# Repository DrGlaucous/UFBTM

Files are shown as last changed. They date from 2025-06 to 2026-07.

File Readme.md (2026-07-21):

# UFBTM
~~*Unnamed Full Body Tracking modules*~~

*They have a name now...*
# Mr. Tracker
A cheap, compact, and open-source realtime tracking module built with slimeVR and the ESP32.

<div style="display: flex;">
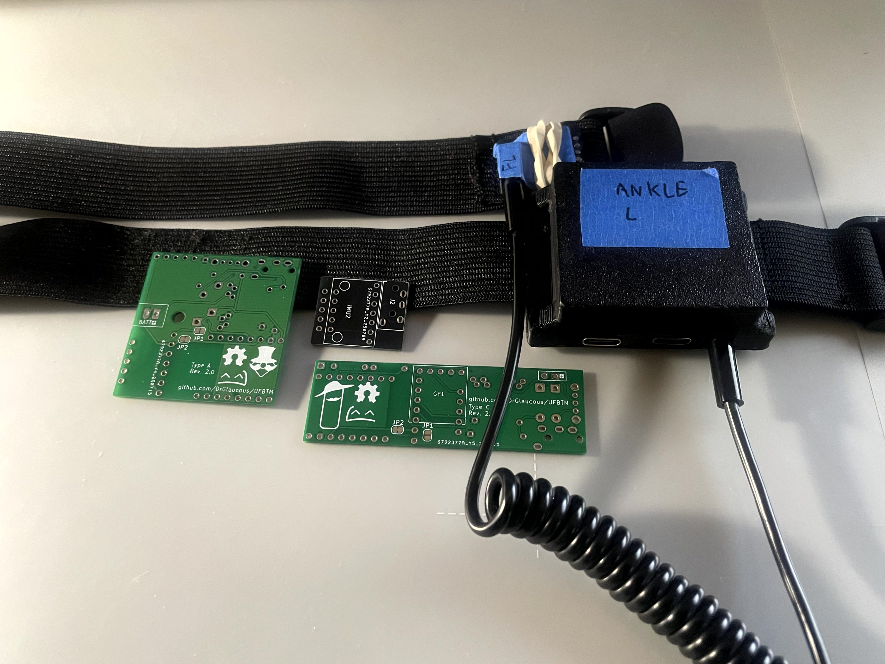
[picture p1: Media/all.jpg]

</div>

## Design goal
<details open>
<summary>
    Details
</summary>

The components for these trackers have been chosen to be **exclusively through-hole** for ease of assembly (at a slight cost of a larger size)

The main IMU this design is based around is the BMI160, primarily for its low cost and small breakout footprint. This IMU is notorious for drifting, so it is also paired with a GY-271 magnetometer to mitigate some of the drift (depending on use location, the magnetometers may need to be disabled due to poor magnetic field).

<figure align = "center">
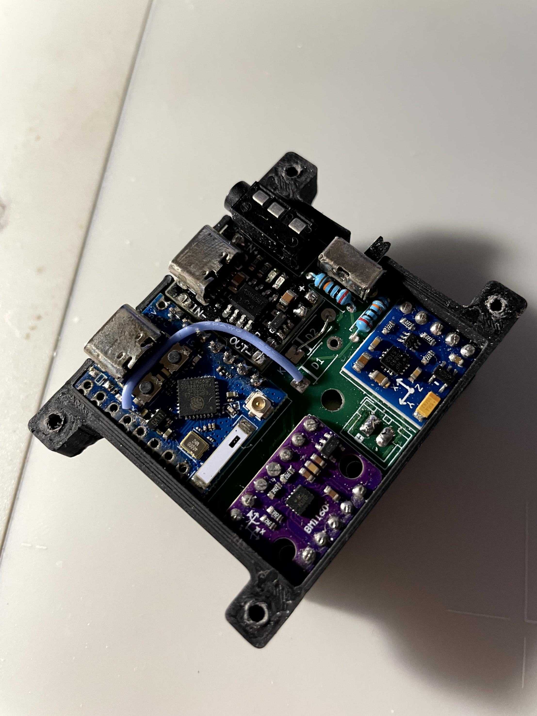
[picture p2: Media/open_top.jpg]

</figure>

This idea is by no means novel; I'm not even the first person to use the components I'm using, but I'm attempting to take a cost approach here. The full tracking set (10 modules + 5 extenders) can potentially be as low as $100 USD without print time costs or filament prices.

Assembly should be quick and reliable with no need for SMD or rework, which is something other modules of this size can't do.

The module uses TRRS (4 ring) aux jacks to connect between the main board and its extender, providing a robust connection that can last many plug cycles and be easily replaced if the wire goes bad.

Battery life of these trackers should be comparable to official ESP8266-based slime trackers, though I've only personally used them for about 6-8 hours at a time.

</details>

## Compatibility

<details>
<summary>
    MCU
</summary>

### MCU
For the microcontroller, this board can support anything with the "superMini" form factor with the 8 or 9 pin length (including the s3 variants, though I haven't tested the firmware with the s3)

<div class="image-row" style="display:flex;flex-wrap:wrap">
    <div class="image-col" style="flex:50%">
        <div class="grid-item">
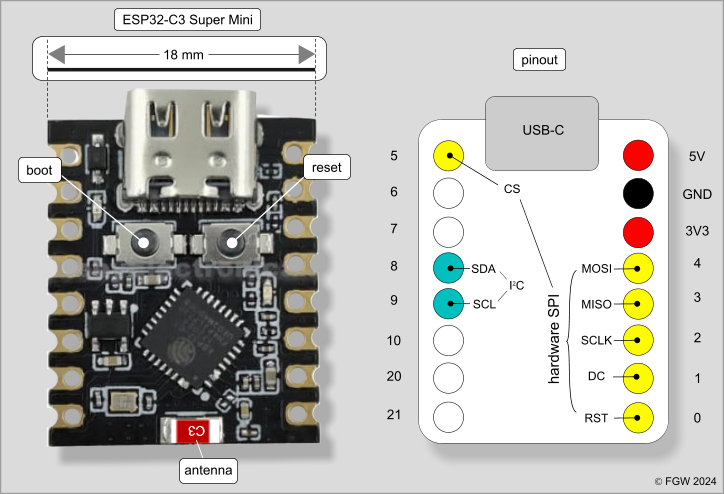
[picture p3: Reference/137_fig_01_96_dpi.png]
            
        </div>
    </div>
    <div class="image-col" style="flex:50%">
        <div class="grid-item">
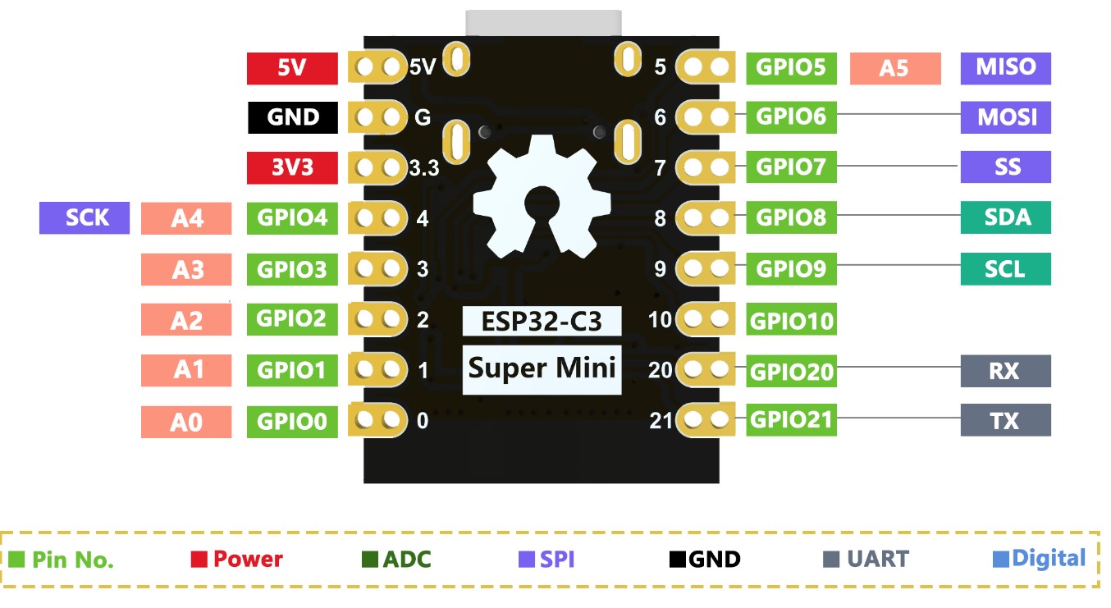
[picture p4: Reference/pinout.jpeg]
            
        </div>
    </div>
</div>

> [!NOTE]
> ***Check to make sure the +5v, GND, and +3.3v on the board match the "standard" superMini layout as seen above! Some boards like to mix them around, like the one below. That one WILL NOT WORK.***

<figure align = "center">
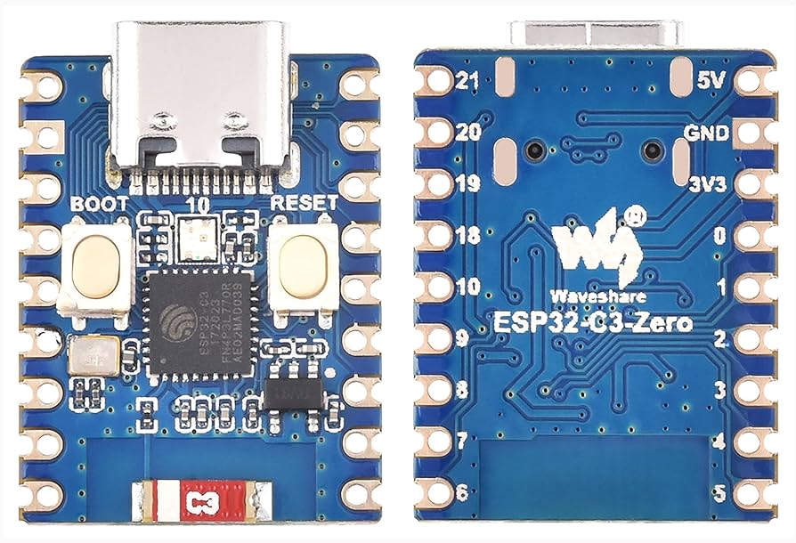
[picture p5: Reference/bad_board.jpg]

<figcaption align = "center"><i>Note how the power pins are on the opposite side from the normal superMini board</i></figcaption>
</figure>

---
My preference is the variant commonly labeled as "Pro Minis" or "C3 Minis" because [the normal "Supermini" modules can have issues with antenna reception](https://peterneufeld.wordpress.com/2025/03/04/esp32-c3-supermini-antenna-modification/), depending on which ones you get. *(and it's a mixed bag, so you're never really sure if you're getting the right ones)*

The "Pro Mini" modules have a larger antenna that seems further spaced from the rest of the components. They're distinct enough that you always know you're getting the right type of board, and as far as I can tell, haven't been complained about online. They also have a place for an external antenna, should you ever want to go that route. SuperMini v2 modules also work well, but are typically more expensive.

<figure align = "center">
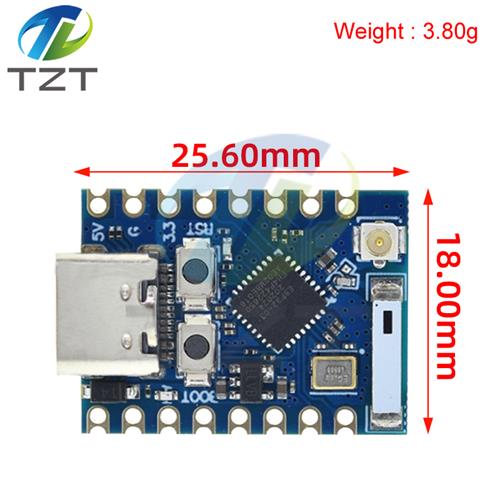
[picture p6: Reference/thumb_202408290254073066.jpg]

<figcaption align = "center"><i>An example of an "ESP32 C3 pro mini"</i></figcaption>
</figure>

</details>

---

<details>
<summary>
    IMU
</summary>

### IMU
The IMU can be anything that matches the BMI160 breakout form-factor.
This includes:
- The BMI160 itself
- The LSM6DS3 (*note: getting these from AliExpress will often just get you a re-badged BMI160.*) These aren't officially supported by the upstream slimeVR firmware as-of-writing, but are supported by my custom fork.
- Slimevr "Mumo" boards hosting a CM-45686 module
- [Mofflab](https://moffshop.deyta.de/products/lsm6dsv-module) LSM6DSV modules *(I'm sure there are other vendors of these that I haven't mentioned, but these are all I could find while searching the internet. Join the SVR discord if you want to find better sources)*

<div class="image-row" style="display:flex;flex-wrap:wrap">
    <div class="image-col" style="flex:50%">
        <div class="grid-item">
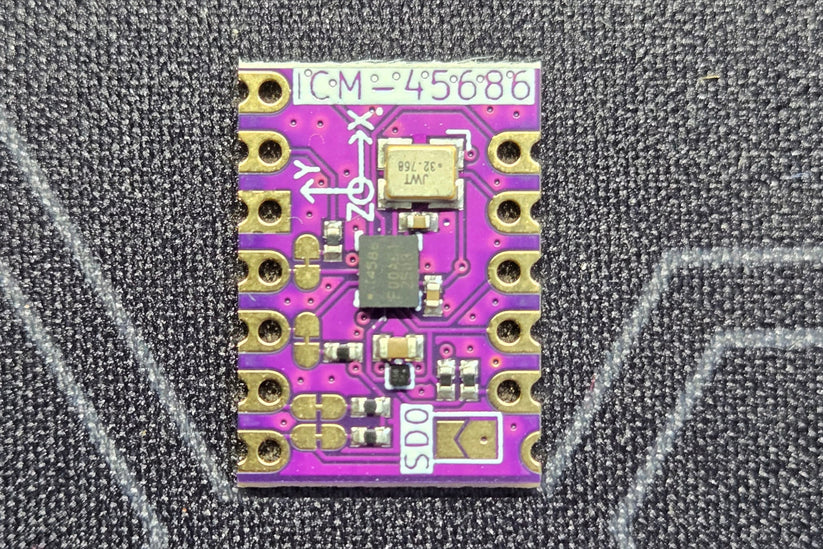
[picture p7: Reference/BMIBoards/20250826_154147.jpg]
            
        </div>
        <div class="grid-item">
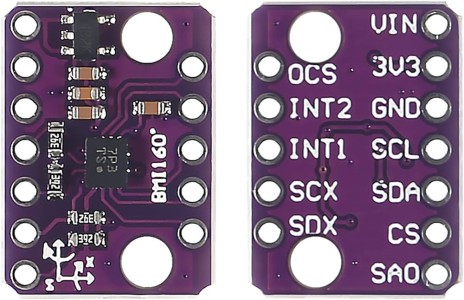
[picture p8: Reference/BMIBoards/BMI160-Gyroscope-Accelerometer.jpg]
            
        </div>
    </div>
    <div class="image-col" style="flex:50%">
        <div class="grid-item">
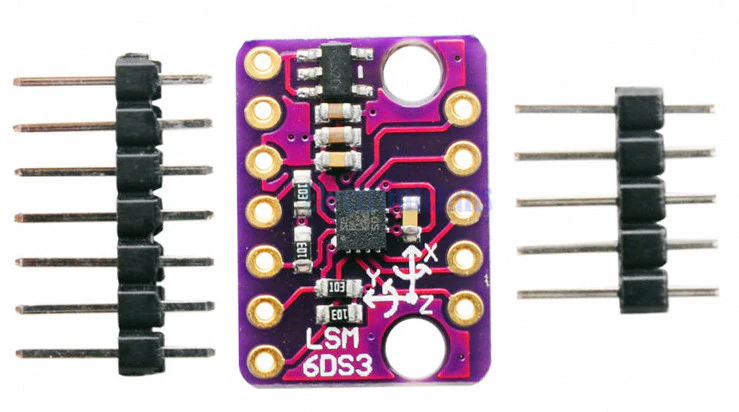
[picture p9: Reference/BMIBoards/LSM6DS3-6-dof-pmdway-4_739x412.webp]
            
        </div>
        <div class="grid-item">
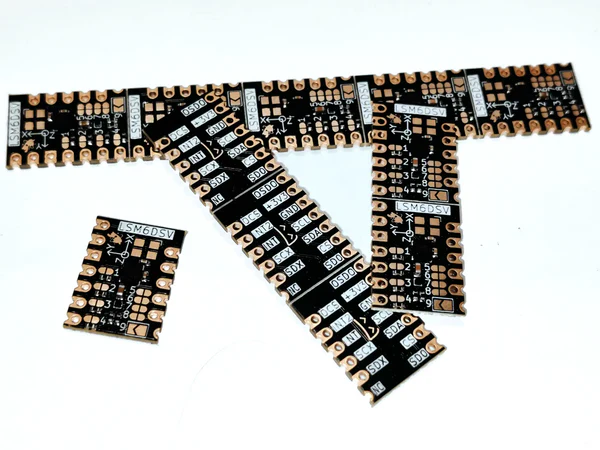
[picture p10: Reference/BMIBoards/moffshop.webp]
            
        </div>
    </div>
</div>

</details>

---

<details>
<summary>
    Magnetometer
</summary>

### Magnetometer

The PCB was designed to hold a GY-271 magnetometer breakout board.
These boards are common enough, but tend to have several variants of actual magnetometer on them, including:
- HMC5883L
- QMC5883L
- QMC5883P

All these are supported by my fork of the slimeVR firmware *(with the BMI160 and LSM6DS3, I haven't tested with the mumos or mofflab boards, but if the IMU on those are good enough, you shouldn't need a magnetometer anyway)*, but they have distinct registers, so you will have to check which one you have. (as-of-writing, the QMC5883P is the most common of these)

<figure align = "center">
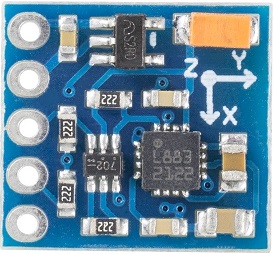
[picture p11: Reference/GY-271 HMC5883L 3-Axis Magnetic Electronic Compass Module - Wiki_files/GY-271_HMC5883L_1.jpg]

</figure>

</details>

---

<details>
<summary>
    Charger
</summary>

### Charger

One of the most compact jellybean chargers are the `LX-LBES` chargers. They tend to come in 2 distinct sizes, and it's unreliable which one you might get. The PCB can support either of them though, so this shouldn't be a problem. These are also commonly labeled as `TP4057` charger boards.

Just make sure it's the `LX-LBES` module and not the other variants like the `LX-MILC` or `LX-LBC3`, both of which are similarly sized, but are incompatible.

<figure align = "center">
<div class="image-row" style="display:flex;flex-wrap:wrap">
    <div class="image-col" style="flex:50%">
        <div class="grid-item">
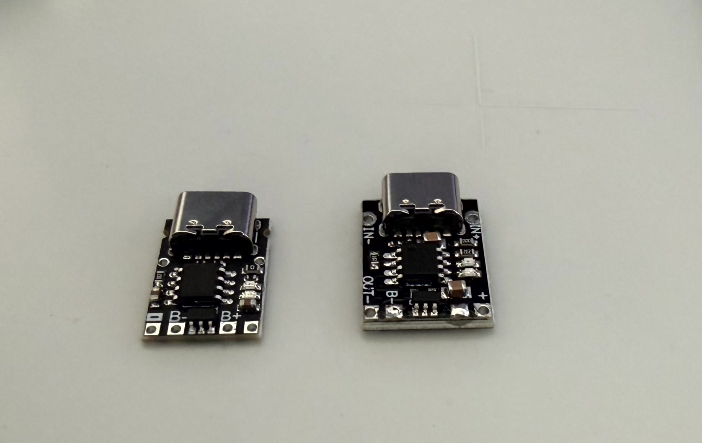
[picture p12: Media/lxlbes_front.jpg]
            
        </div>
    </div>
    <div class="image-col" style="flex:50%">
        <div class="grid-item">
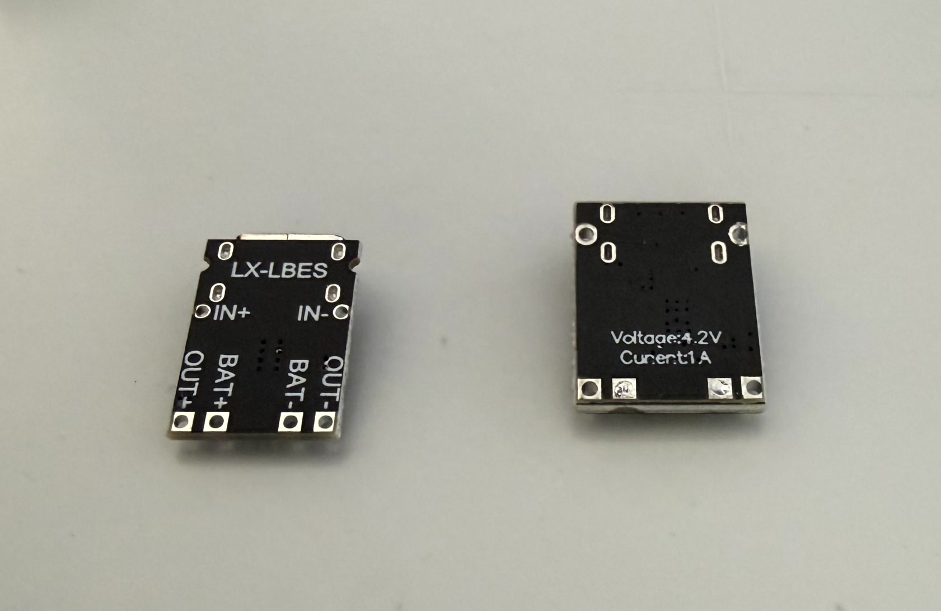
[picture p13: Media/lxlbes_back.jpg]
            
        </div>
    </div>
</div>
<figcaption align = "center"><i>On the left: the smaller of the two LX-LBES boards, on the right: the more common larger variant. Both of these will work for these trackers</i></figcaption>
</figure>

<figure align = "center">
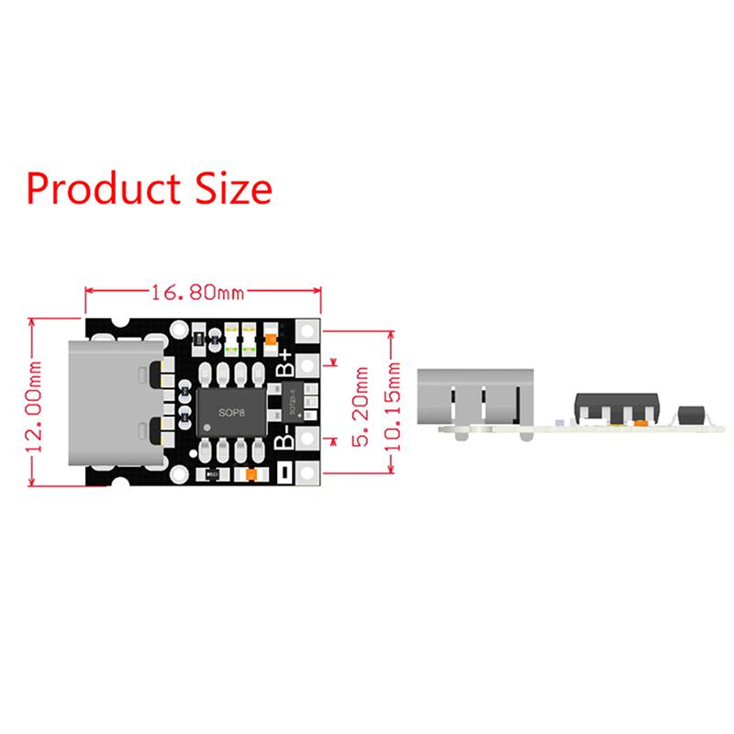
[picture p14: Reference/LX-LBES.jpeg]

</figure>

</details>

---

<details>
<summary>
    Battery
</summary>

### Battery

This tracker is designed to work with 2 distinct battery sizes:
- The 804040 (a square flat-pack, used with Mr. Tracker PCBs)
- The 18650 (a common cylindrical battery, used with Mrs. Tracker PCBs)

Unfortunately, I have not modeled a housing for the 18650 variant yet.

18650 batteries are cheaper than the 804040s, especially if you get them used from a place like [batteryhookup](https://batteryhookup.com/), where they cost about 50c per battery. Depending on the quality of the cell, they can also hold more charge than the 804040s, but as a trade-off are inconveniently shaped for trackers. The Mrs. Tracker PCB is designed to accommodate these long, skinny batteries as best as possible.

<figure align = "center">
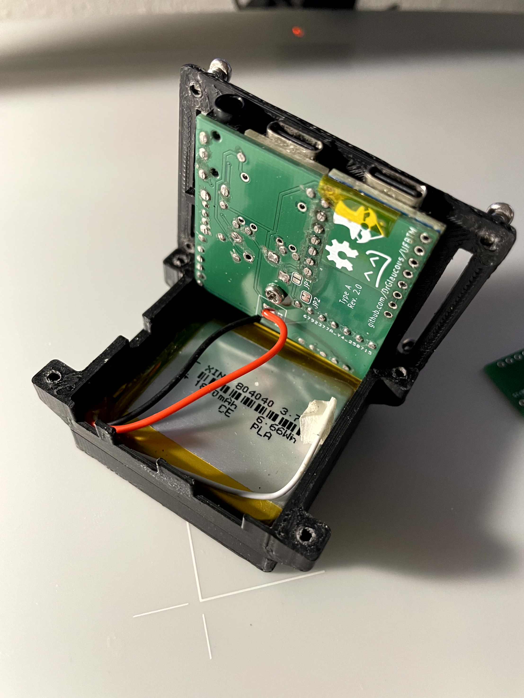
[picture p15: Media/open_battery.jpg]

</figure>

</details>

---

<details>
<summary>
    LDO
</summary>

### LDO

The LDO regulates the incoming battery voltage down to 3.3 volts for the electronics. The board will accept any LDO in a TO-92 package, but was designed around the HT7333 regulator as that is what I could get off Amazon.

If the LDO you select has a different pinout than the HT7333, then you will need to reconfigure the jumpers as described in [Power configuration](#power-configuration).

<figure align = "center">
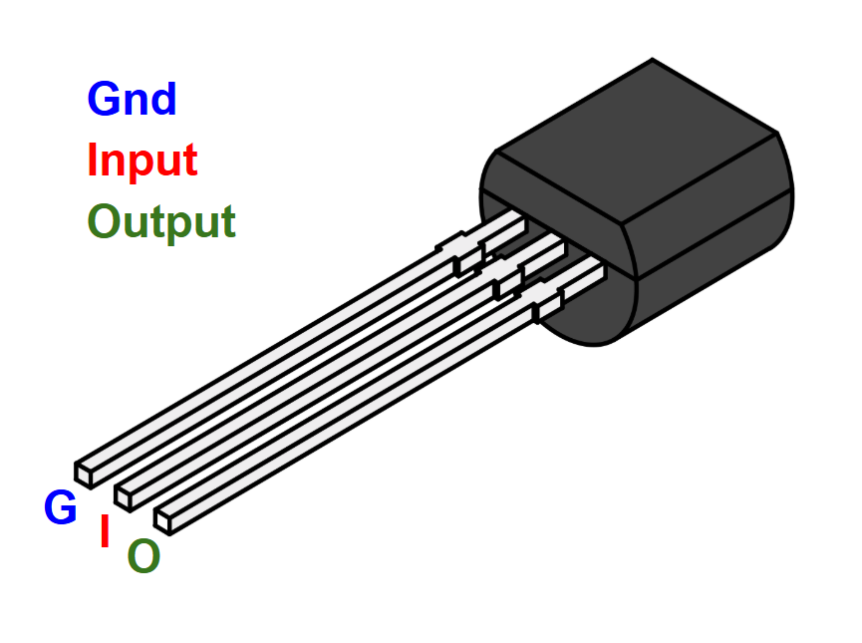
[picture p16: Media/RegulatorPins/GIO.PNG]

</figure>

This part is optional if your IMU has a built-in 5v to 3.3v regulator **that can support the currents required by the ESP32 and other componets**. I've seen some that both could and couldn't, so I'd assume the worst case and use a discrete LDO for safety.

The MCP1700 also shares the same pinout and is rated at 250mA.

#### Capacitor requirements
Many of these LDOs require an inline capacitor for voltage smoothing and stable output (for example, the datasheet for the MCP1700 regulator says it requires at least a 1uf capacitor). I was able to find 10uf ceramic capacitors to use in my design, but you may be able to get away with smaller values, or even none at all. The HT7333 worked without a capacitor too, but it would have trouble slightly sooner than with a capacitor when the battery voltage got too low.

</details>

## Bill of Materials

Prices are generally cheaper if you buy in bulk from China, which is recommended since you'll likely be building at least five of these and need to order the PCBs from there anyway. (unless you *have* to use a domestic PCB manufacturer, in which case you'll probably end up paying several times more than ordering through a provider like JLCPCB)
Most of this stuff should be available to get on Amazon as well, albeit more expensive.

I've added some links to the BOMs below to help new builders get started, but there might be better deals for the same parts with some shopping around, which I encourage you to do.

> [!NOTE]
> ***Some of the links below have multiple options on the listing (like the resistors for instance. Make sure you choose the correct type!)***

### Mr/Mrs. Tracker part list
---
|part|qty per tracker|qty per package (typical)|price per package (typical, USD)|Link (non-affiliate, U.S. domain, may be expired)|
|-|-|-|-|-|
|PCB (ordered from PCB provider)|1|5-20|~$10 excluding shipping|[JLCPCB](https://jlcpcb.com/)|
|ESP32 C3 [(see compatible devices)](#mcu)|1|1|~$2.5|[AliExpress](https://www.aliexpress.us/item/3256808596276264.html)
|IMU [(see compatible devices)](#imu)|1|1|~$2.5|[AliExpress](https://www.aliexpress.us/item/3256806936640318.html)
|GY-271 Magnetometer [(see compatible devices)](#magnetometer) *(optional, but recommended to limit drift)*|1|1|~$2|[AliExpress](https://www.aliexpress.us/item/3256808812894856.html)
|LX-LBES li-ion charger [(see compatible devices)](#charger)|1|5-10|~$5|[AliExpress](https://www.aliexpress.us/item/3256807364882965.html)
|3.3v LDO [(see compatible devices)](#ldo)|1|20-100|~$3|[AliExpress](https://www.aliexpress.us/item/3256807332164741.html)
|10uF Ceramic Capacitor [(maybe optional, see LDO)](#capacitor-requirements)|1|100|~$3|[AliExpress](https://www.aliexpress.us/item/3256809085304078.html)
|200K resistor (for voltmeter)|2|100|~$2|[AliExpress](https://www.aliexpress.us/item/3256802310109990.html)
|On-Off Switch (SK12D07VG4)|1|100|~$2|[AliExpress](https://www.aliexpress.us/item/2251832696379644.html)
|TRRS Connector (PJ-320A) *(Optional, for extenders)*|1|20|~$2|[AliExpress](https://www.aliexpress.us/item/2255800974971563.html)
|M2.5x6 self tapping screws|5|50|~$2|[AliExpress](https://www.aliexpress.us/item/3256805374708201.html), [Amazon](https://a.co/d/0iR6Q6Wc)
|804040 battery|1|5|~$18 USD|[AliExpress](https://www.aliexpress.us/item/3256806179780660.html)
|Elastic straps, 25mm wide|Varies|5 Meters|~$4|[AliExpress](https://www.aliexpress.us/item/2251832835409359.html)
|Strap Buckles, 25mm wide|1|5|~$5|[AliExpress](https://www.aliexpress.us/item/3256805860301514.html)
|Sewing thread for attaching buckles to straps|Varies|Varies|N.A.|N.A.
|Plastic housing|1|N.A.|N.A.|N.A.

### Extender (Tracker Jr) part list
---

|part|qty per tracker|qty per package (typical)|price per package (typical, USD)|Link (non-affiliate, U.S. domain, may be expired)|
|-|-|-|-|-|
|PCB (ordered from PCB provider)|1|5-20|~$10 excluding shipping|[JLCPCB](https://jlcpcb.com/)|
|IMU [(see compatible devices)](#imu)|1|1|~$2.5|[AliExpress](https://www.aliexpress.us/item/3256806936640318.html)
|GY-271 Magnetometer [(see compatible devices)](#magnetometer) *(optional, but recommended to limit drift)*|1|1|~$2|[AliExpress](https://www.aliexpress.us/item/3256808812894856.html)
|TRRS Connector (PJ-320A)|1|20|$2|[AliExpress](https://www.aliexpress.us/item/2255800974971563.html)
|TRRS Male-Male Aux cable, 1 meter|1|1|$2|[AliExpress](https://www.aliexpress.us/item/3256805991501373.html)
|Elastic straps, 25mm wide|Varies|5 Meters|$4|[AliExpress](https://www.aliexpress.us/item/2251832835409359.html)
|Strap Buckles, 25mm wide|1|5|~$5|[AliExpress](https://www.aliexpress.us/item/3256805860301514.html)
|Sewing thread for attaching buckles to straps|Varies|Varies|N.A.|N.A.
|Plastic housing|1|N.A.|N.A.|N.A.

## Power configuration

<details>
<summary>
    Details
</summary>

Rev. 3 boards have several jumpers on the underside that changes how the device can be powered so a wider range of parts can be used.

Depending on the quality of the IMU breakout board, the linear regulator and voltage smoothing capacitor may not be needed. This varies more than you'd think with distributors though, so it's not always safe to count on it. Additionally, some versions of the IMU breakout might not even have an integrated regulator at all, making the discrete regulator required.

- Jumpers `A`, `B`, `C`, and `D` alter the pinout for the voltage regulator and allow one with any pin arrangement to be installed.
- Connecting jumper `E` allows the board to use the voltage regulator on the IMU instead of the discrete one.
- Connecting jumper `F` allows the ESP32's USB port to charge the battery. The drawback is that charging the tracker will *always* turn on the ESP32, wasting power and charging slower.

The following is a table of all the possible voltage regulator pinouts and their corresponding jumper configs. An "O" means to leave the jumper at default (bridging positions 1 and 2), an "X" means to cut the jumper and flip it (bridging positions 2 and 3). "Flip" means to solder the regulator into the socket backwards 

>[!NOTE]
> Although I tried to keep the ABCD jumpers next to each other, their orientations are flipped! Pay close mind to what side of the jumper pad the "1" and "3" are on in the silkscreen!

|Pinout|A|B|C|D|Flip|
|-|-|-|-|-|-|
||O|O|O|O|O|
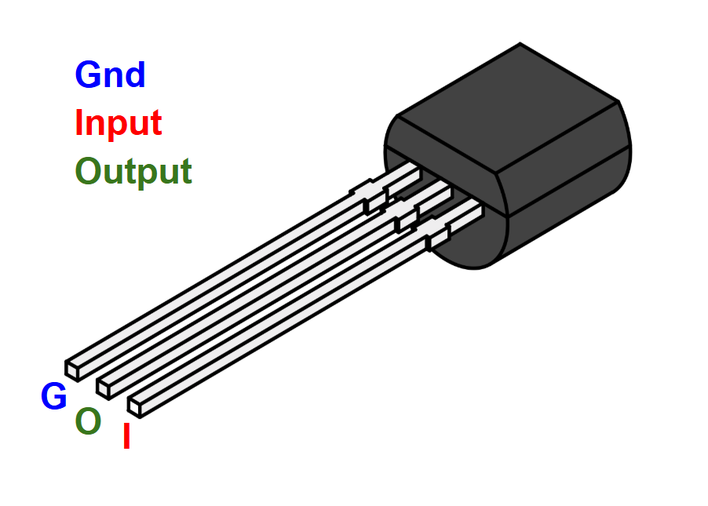
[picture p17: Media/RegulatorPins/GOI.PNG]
||O|O|X|X|O|
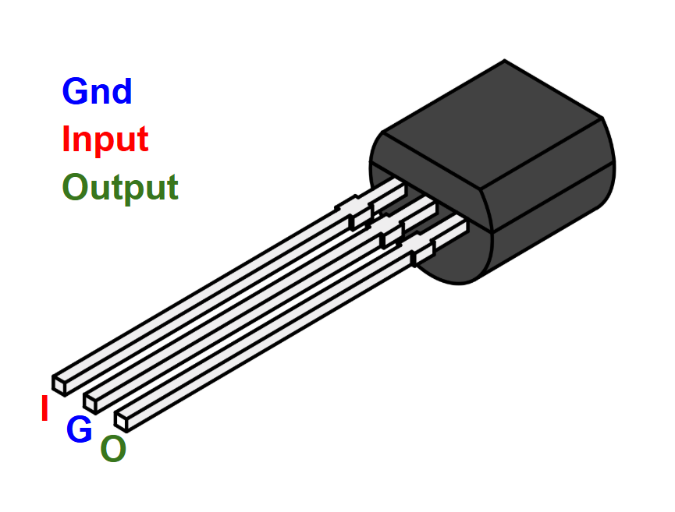
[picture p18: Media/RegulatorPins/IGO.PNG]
||X|X|O|O|O|
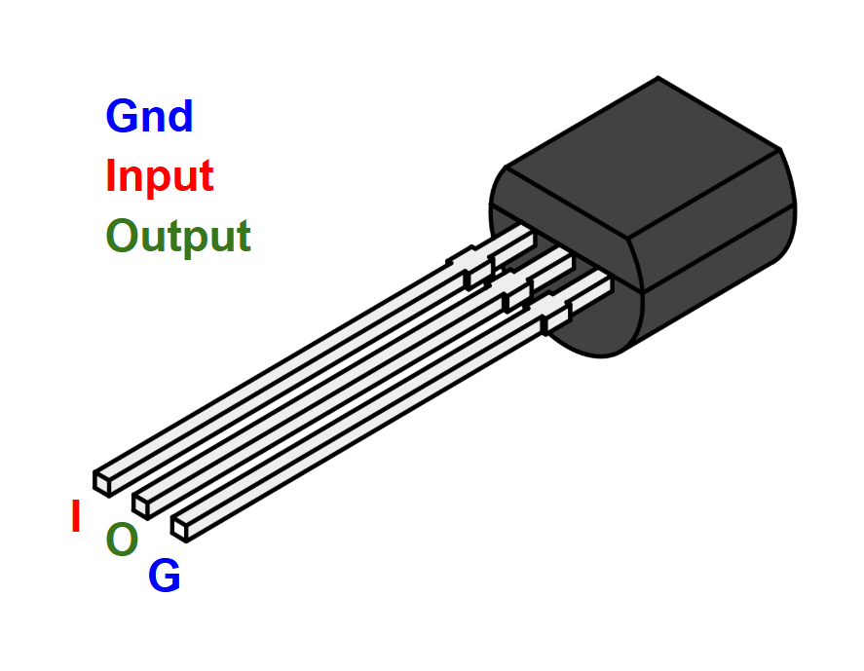
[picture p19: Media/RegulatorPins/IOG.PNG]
||X|X|O|O|X|
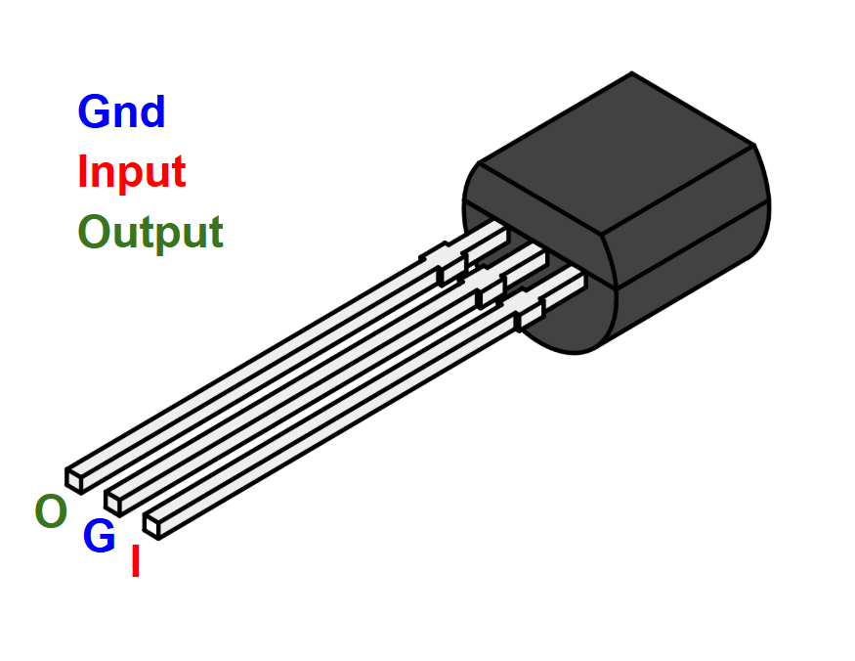
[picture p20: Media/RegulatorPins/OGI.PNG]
||O|O|X|X|X|
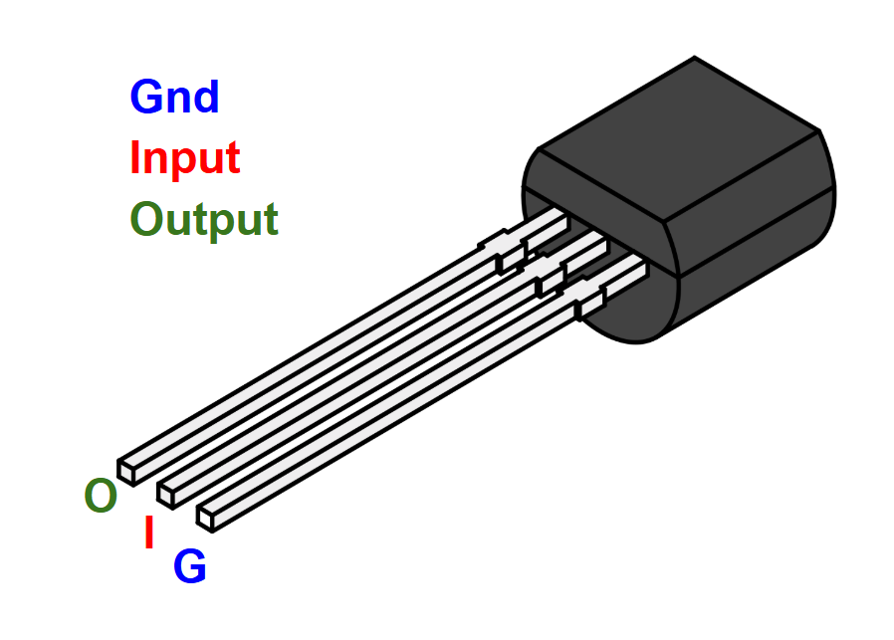
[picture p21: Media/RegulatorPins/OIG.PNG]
||O|O|O|O|X|

In a nutshell,
- AB flip 1 and 2,
- CD flip 2 and 3

</details>

---

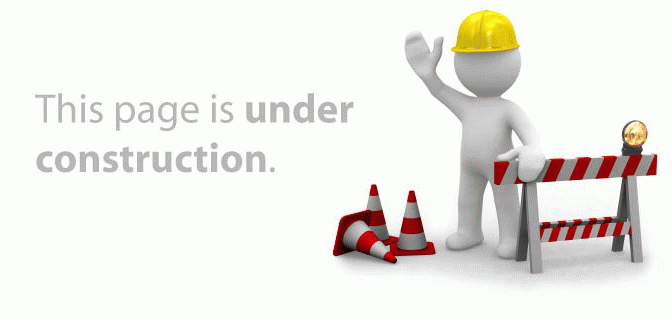
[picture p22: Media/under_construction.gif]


> [!CAUTION]
> Everything below this point is very unfinished (as opposed to only slightly unfinished, as is seen above)

## Ordering PCBs

todo: this

## Recommended tools for assembly

In theory, these trackers can be assembled just fine with a [Wal-Mart special](https://www.walmart.com/ip/EverStart-Soldering-Iron-Model-5133-Red-120V-30W-Automotive-Electrical-Tool-New/744820237) *(link included for meme purposes only!)* soldering iron, a pair of children's safety scissors, a manicure file, and a sewing needle. Will you have a good time doing it? No, but it's definitely possible.

Instead of that, here's the list of tools I recommend to make assembly of these go smoothly:

- A Soldering Iron (the Wal-Mart special will work, but I suggest getting something at least partway decent on Amazon; good soldering irons can be had for less than $30.)
- Solder (lead solder is easier to work with, but lead-free works OK too if you're cautious about working with lead.)
- Flush cutters
- A needle file set (optional)
- SMD Tweezers
- Helping hands vice (optional)
- Small phillips screwdriver (for the screws on the housing)

For the straps:
- A pair of scissors (preferably not child safety ones)
- A lighter
- A sewing needle or sewing machine
- Sewing thread

## Assembly Preface

These guides assume you have everything in hand required to build one of these trackers.

Typically, a good rule of thumb is to start with the lowest profile components first and work your way up by height. Most of the stuff on these trackers is the same height however, so order isn't ultra-important; nothing really gets in the way of anything else, but regardless, I still like to start with the breakout boards *(MCU, IMU, Magnetometer, and Charger)*.

To keep the tracker as compact as possible, the breakouts are soldered directly on top of the board. This makes them much more difficult to remove though, so be careful during assembly!

I've had an IMU come to me dead on arrival and had to go through the painstaking process of desoldering it from the board. (which involved simultaneously heating the pins and wedging an xacto between the IMU and the PCB)
Because of that, I like to make sure that parts work beforehand by soldering up a test rig with removable pins to test parts with.

Working with a breadboard for testing is feasible too, but it's less likely that people would just have one of those onhand, much less the desire to wire an entire setup just to see if a few parts maybe don't work.

## Assembly (Mr. Tracker)

<details>
<summary>
    Details
</summary>

</details>

## Assembly (Mrs. Tracker)

## Assembly (Tracker Jr)

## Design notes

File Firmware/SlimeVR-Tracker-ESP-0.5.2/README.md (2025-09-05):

# SlimeVR Tracker firmware for ESP

## What is this Fork?

This fork adds (potential? I can't actually test firsthand...) support for the LSD6DS3 IMU module under sensor fusion and fixes various bugs with the BMI160 + Magnetometer code. I've also added support for the qmc5883p magnetometer breakout, the latest knockoff to the HMC5883L and commonly marketed as such. These usually appear on the GY-271 breakout boards.

I used 0.5.2 instead of a newer version because this version works stably on the ESP32C3 superminis I'm using with my specific homebuilt trackers (Mr and Ms tracker).

## Description

Firmware for ESP8266 / ESP32 microcontrollers and different IMU sensors to use them as a vive-like trackers in VR.

Requires [SlimeVR Server](https://github.com/SlimeVR/SlimeVR-Server) to work with SteamVR and resolve pose. Should be compatible with [owoTrack](https://github.com/abb128/owo-track-driver), but is not guaranteed.

## Configuration

Firmware configuration is located in the `defines.h` file. For more information on how to configure your firmware, refer to the [Configuring the firmware project section of SlimeVR documentation](https://docs.slimevr.dev/firmware/configuring-project.html).

## Compatibility

The following IMUs and their corresponding `IMU` values are supported by the firmware:
* BNO085 & BNO086 (IMU_BNO085)
  * Using any fusion in internal DMP. Best results with ARVR Stabilized Game Rotation Vector or ARVR Stabilized Rotation Vector if in good magnetic environment.
* BNO080 (IMU_BNO080)
  * Using any fusion in internal DMP. Doesn't have BNO085's ARVR stabilization, but still gives good results.
* MPU-6500 (IMU_MPU6500) & MPU-6050 (IMU_MPU6050)
  * Using internal DMP to fuse Gyroscope and Accelerometer. Can drift substantially.
  * NOTE: Currently the MPU will auto calibrate when powered on. You *must* place it on the ground and *DO NOT* move it until calibration is complete (for a few seconds). **LED on the ESP will blink 5 times after calibration is over.**
* BNO055 (IMU_BNO055)
  * Performs much worse than BNO080, despite having the same hardware. Not recommended for use.
* MPU-9250 (IMU_MPU9250)
  * Using Mahony sensor fusion of Gyroscope, Magnetometer and Accelerometer, requires good magnetic environment.
  * See *Sensor calibration* below for info on calibrating this sensor.
  * Specify `IMU_MPU6500` in your `defines.h` to use without magnetometer in 6DoF mode.
  * Experimental support!
* BMI160 (IMU_BMI160)
  * Using sensor fusion of Gyroscope and Accelerometer.
  * **See Sensor calibration** below for info on calibrating this sensor.
  * Calibration file format is unstable and may not be able to load using newer firmware versions.
  * Experimental support!
  * Support for the following magnetometers is implemented (even more experimental): HMC5883L, QMC5883L.
* ICM-20948 (IMU_ICM20948)
  * Using fusion in internal DMP for 6Dof or 9DoF, 9DoF mode requires good magnetic environment.
  * Comment out `USE_6DOF` in `debug.h` for 9DoF mode.
  * Experimental support!
* BMI270 (IMU_BMI270), ICM-42688 (IMU_ICM42688), LSM6DS3TR-C (IMU_LSM6DS3TRC), LSM6DSV (IMU_LSM6DSV), LSM6DSO (IMU_LSM6DSO), LSM6DSR (IMU_LSM6DSR), MPU-6050 (IMU_MPU6050_SF)
  * Using common code: SoftFusionSensor for sensor fusion of Gyroscope and Accelerometer.
  * Gyro&Accel sample rate, gyroscope offset and 6-side accelerometer calibration supported.
  * In case of BMI270, gyroscope sensitivity auto-calibration (CRT) is additionally performed.
  * Support for magnetometers is currently not implemented.
  * VERY experimental support!

Firmware can work with both ESP8266 and ESP32. Please edit `defines.h` and set your pinout properly according to how you connected the IMU.

## Sensor calibration

*It is generally recommended to turn trackers on and let them lay down on a flat surface for a few seconds.** This will calibrate them better.

**Some trackers require special calibration steps on startup:**
### MPU-9250
  * Turn them on with chip facing down. Flip up and put on a surface for a couple of seconds, the LED will light up.
  * After a few blinks, the LED will light up again
  * Slowly rotate the tracker in an 8-motion facing different directions for about 30 seconds, while LED is blinking
  * LED will turn off when calibration is complete
  * You don't have to calibrate next time you power it on, calibration values will be saved for the next use

### BMI160

  If you have any problems with this procedure, connect the device via USB and open the serial console to check for any warnings or errors that may indicate hardware problems.

  - **Step 0: Power up with the chip facing down.** Or press the reset/reboot button.

    > The LED will be lit continuously. If you have the tracker connected via USB and open the serial console, you will see text prompts in addition to the LEDs. You can only calibrate 1 IMU at a time.

    Flip it back up while the LED is still solid. Wait a few seconds, do not touch the device.
    
  - **Step 1: It will flash 3 times when gyroscope calibration begins.**

    > If done incorrectly, this step is the most likely source of constant drift.

    Make sure the tracker does not move or vibrate for 5 seconds - still do not touch it.

  - **Step 2: It will flash 6 times when accelerometer calibration begins.**

    > The accelerometer calibration process requires you to **hold the device in 6 unique orientations** (e.g. sides of a cube),
    > keep it still, and not hold or touch for 3 seconds each. It uses gravity as a reference and automatically detects when it is stabilized - this process is not time-sensitive.

    > If you are unable to keep it on a flat surface without touching, press the device against a wall, it does not have to be absolutely perfect.

    **There will be two very short blinks when each position is recorded.**
    
    Rotate the device 90 or 180 degrees in any direction. It should be on a different side each time. Continue to rotate until all 6 sides have been recorded.
    
    The last position has a long flash when recorded, indicating exit from calibration mode.

  #### Additional info for BMI160
  - For best results, **calibrate when the trackers are warmed up** - put them on for a few minutes,
    wait for the temperature to stabilize at 30-40 degrees C, then calibrate.
    Enable developer mode in SlimeVR settings to see tracker temperature.

  - There is a legacy accelerometer calibration method that collects data during in-place rotation by holding it in hand instead.
    If you are absolutely unable to use the default 6-point calibration method, you can switch it in config file `defines_bmi160.h`.

  - For faster recalibration, you disable accelerometer calibration by setting `BMI160_ACCEL_CALIBRATION_METHOD` option to `ACCEL_CALIBRATION_METHOD_SKIP` in `defines_bmi160.h`.
    Accelerometer calibration can be safely skipped if you don't have issues with pitch and roll.
    You can check it by enabling developer mode in SlimeVR settings (*General / Interface*) and going back to the *"Home"* tab.
    Press *"Preview"* button inside the tracker settings (of each tracker) to show the IMU visualizer.
    Check if pitch/roll resembles its real orientation.

  - Calibration data is written to the flash of your MCU and is unique for each BMI160, keep that in mind if you have detachable aux trackers.

## Uploading On Linux

Follow the instructions in this link [PlatformIO](https://docs.platformio.org/en/latest//faq.html#platformio-udev-rules), this should solve any permission denied errors

## Extra notes for me

How to configure magnetometer mapping:

- Hack out the firmware to replace the acceleration-get code with magnetometer-get code (add acceleration update to `onMagRawSample`)
- Upload the code to the controller, it will obviously break quite a few things, but the acceleration vector as seen in the slimeVR view will now the what direction the tracker thinks the magnetometer is.
- (optionally) use a smartphone or similar device to see what the magnetic vector field in the local area is.
- rotate the physical device so that one of the sides is in the same direction as that vector field.
- see if the acceleration in the window matches this (if not, make note of what axis is really is, or if it's flipped)
- repeat for all 3 axis and then re-adjust the mapping config in `defines.h`

## Contributions
Any contributions submitted for inclusion in this repository will be dual-licensed under
either:

- MIT License ([LICENSE-MIT](/LICENSE-MIT))
- Apache License, Version 2.0 ([LICENSE-APACHE](/LICENSE-APACHE))

Unless you explicitly state otherwise, any contribution intentionally submitted for
inclusion in the work by you, as defined in the Apache-2.0 license, shall be dual
licensed as above, without any additional terms or conditions.

You also certify that the code you have used is compatible with those licenses or is
authored by you. If you're doing so on your work time, you certify that your employer is
okay with this and that you are authorized to provide the above licenses.

For an explanation on how to contribute, see [`CONTRIBUTING.md`](CONTRIBUTING.md)

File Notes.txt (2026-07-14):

BMI160 chip shcematic:

See:
https://www.bosch-sensortec.com/media/boschsensortec/downloads/datasheets/bst-bmi160-ds000.pdf
SCX is the clock for SPI/I2C

SDX is:
MOSI for SPI4
SISO for SPI3
SDA for I2C

~~~~~~~~~~~~~~~~~~~~~
pin to breakout transaltions for BMI160:
[chip pin]: [breakout pin]
SDO: SAO (main i2c address, pulled up)
ASDX: SDX (magnetometer i2c, no resistor)
ASCX: SCX (magnetometer i2c, no resistor)
INT1: INT1
VDDIO: Regulated Vin (from LDO) - VIN
GNDIO: GND
GND: GND
VDD: Regulated Vin (from LDO) - VIN
INT2: INT2
OSCB: OCS (for OCS interface, not really used)
OSDO: Not Connected
CSB: CS (chip select for main SPI, pulled up)
SCX: SCL (main i2c, pulled up)
SDX: SDA (main i2c, pulled up)

x4 capacitors between positive and ground
x4 392 resistors, 2 for i2c, and 2 for CS and SAO
~~~~~~~~~~~~~~~~~~~~~

it came out in 2014:
https://www.sensortips.com/featured/imu-targets-tight-spaces/

pin-equivalent alternative:
lsm6ds3
(roughly same price, unsure if its better.)

The GY-271/3 is much more basic;
5-pin interface:
[breakout pin]
VCC (regulated, 3-5V)
GND
SCL (pulled up, in 271, this is boosted to vin levels)
SDA (Pulled up, in 271, this is boosted to vin levels)
DRDY (direct from chip)

~~~~~~~~~~~~~~~~~~~~~

good battery type:
804040
or 804050
[8mm][40mm][50mm]
[80]4050

GY-271 magnometer breakout info
See:
http://wiki.sunfounder.cc/index.php?title=GY-271_HMC5883L_3-Axis_Magnetic_Electronic_Compass_Module

configuring tracker firmware to work with this hardware (BMI160 + HMC/QMC magnetometer)
https://github.com/SlimeVR/SlimeVR-Tracker-ESP/issues/300

The charger modules:
LX-LBES - brand name

simmilar variants:
LN-MLIC
LX-LBC3

the aliexpress couterpart is commonly called the the "TP4057"

good site that provides some info on the components on this module:
https://www.adrirobot.it/caricabatteria-litio-li-ion-step-up-boost-4-28v-regolabile/

switch footprint:
SS12D10 //flat, not as good, can be bumped and turned off
or
SS12D06 //90 deg

also looked into:
SS12F21
and
SK12F14 (this one seems like its the best)
sk22h03
Even better:
SK12D07VG3

note: the last digit in this switch is how long the stick bit is.
I think 3 or 4 mm should be good. (leaning towards 4)

some useful info on charging the module:
https://forum.arduino.cc/t/charging-lithium-ion-battery-using-the-usb-port-on-esp32-c3-supermini-with-tp4056-and-powering-the-esp32-with-the-battery-when-not-connect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

intended behavior:

plugging in device will power it up and charge it, regardless of switch state

battery will only discharge when switch is ON.
battery should be able to be charged regardless of switch state.

using a single connector (data + battery) will mean 

alternatives to the c3 supermini:
ESP32-C3-Zero Pro Mini (bigger PCB antenna, potentially easier to swap to the external one... but that may not be needed, as seen by some tests by others)

https://peterneufeld.wordpress.com/2025/03/04/esp32-c3-supermini-antenna-modification/

Other names for this board:
New Micro ESP32-C3
ESP32-C3_Mini_V1

May need:
uFL antenna 2.4g

If I have gobs of time, (I don't), this would also be interesting to look into for bad wi-fi connections
https://github.com/martin-ger/esp32_nat_router
https://randomnerdtutorials.com/esp32-esp-now-wi-fi-web-server/
https://www.reddit.com/r/esp32/comments/18y9fq0/esp32_connecting_to_a_wifi_network_and_espnow_at/
We could also use esp-now and serial to send packets directly to the handler device without having to go through a home wifi network first

potential connector types:
https://www.mattmillman.com/info/crimpconnectors/common-jst-connector-types/

JST 2.5mm (probably the cheapest and most universal, XH)
or JST 2mm - (ph connector)
or JST ZH ()
jst PH20

or JST 1.25mm
Mini Micro JST-1.25mm

or 5264 connector

or headphone jack (2.5mm)!
PJ-210B
PJ-320A
(these may have a shorting problem... I need to either look into the safest way of routing connections or use a different connector.
A disappointment because otheriwse, they're perfect for my needs)

A USB conector that's obscure so people don't try to plug in a generic connector to it
Mini USB 8P

potential screw type:
m2 x5mm plastic boring screw
(ended up purchasing m2.6x6mm the first round)

final-ish BOM:

BMI160 x 15 (or lsm6ds3 for kicks)
GY 273 x 15
ESP32-C3_Mini_V1 x 10
LX-LBES TP4057 x10
PJ-320A x 10
trrs wire x 5
1n5817 diode x 20
200k resistor x 20
804040 battery x 10
SK12D07VG4 switch x 10

straps + buckles
plastic screws
male usb-c connectors (or a cheap hub + cables? $14 for something capable of hitting all the units at once) (going the premade hub + cord route here)

plastic screws:

(I.E. self-tapping scews)
nerf screws are commonly m2.6 x X...

m2.6 x 6
imperial equivalent:
#3 x 1/4

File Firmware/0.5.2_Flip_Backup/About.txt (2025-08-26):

I didn't see that you could remap gyro axis. oops.

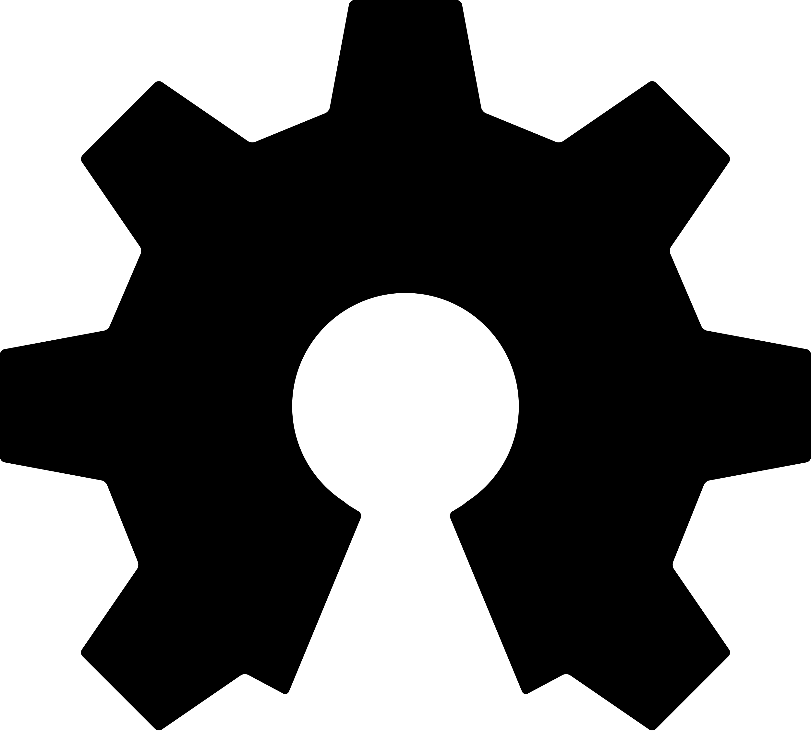
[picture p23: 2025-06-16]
Media/Silkscreen/open-source-hardware-1.png

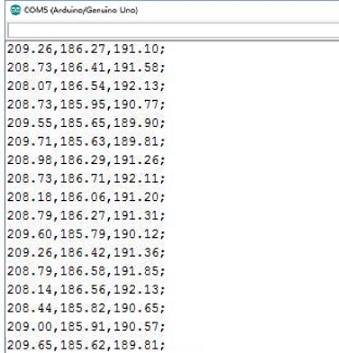
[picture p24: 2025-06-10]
Reference/GY-271 HMC5883L 3-Axis Magnetic Electronic Compass Module - Wiki_files/GY-271_HMC5883L_4.jpg

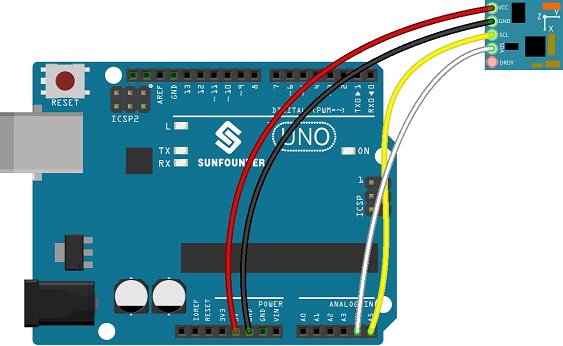
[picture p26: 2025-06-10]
Reference/GY-271 HMC5883L 3-Axis Magnetic Electronic Compass Module - Wiki_files/GY-271_HMC5883L_3.jpg

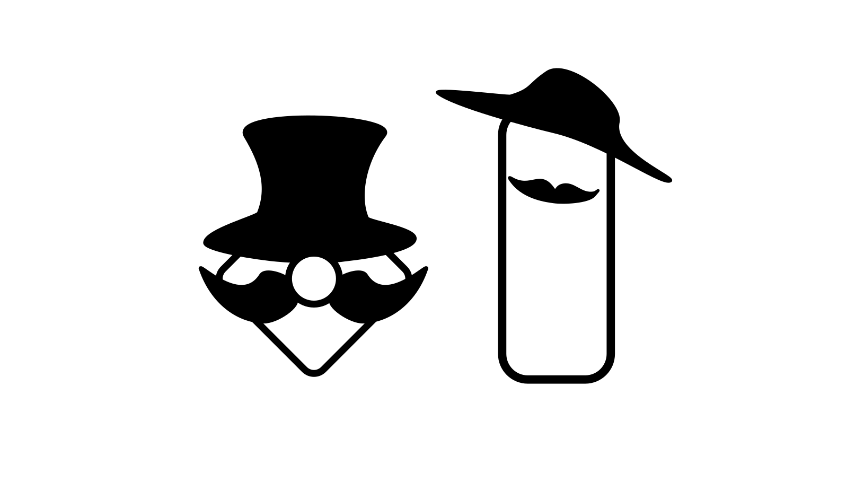
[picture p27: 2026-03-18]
Media/Silkscreen/Thumbnail.PNG

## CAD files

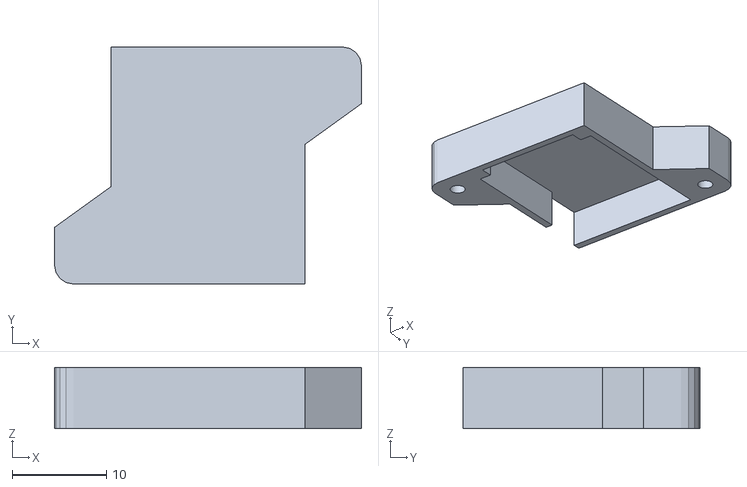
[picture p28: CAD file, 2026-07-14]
CAD/STL/Extender_v2_Cap.stl
32.5 x 25.1 x 6.50

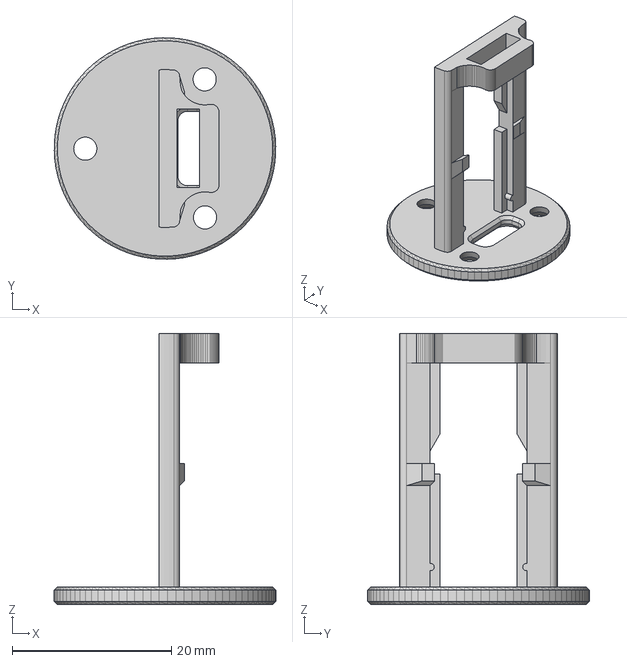
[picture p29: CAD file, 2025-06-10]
Reference/LX-LBES.step
27.8 x 27.8 x 34.0 mm

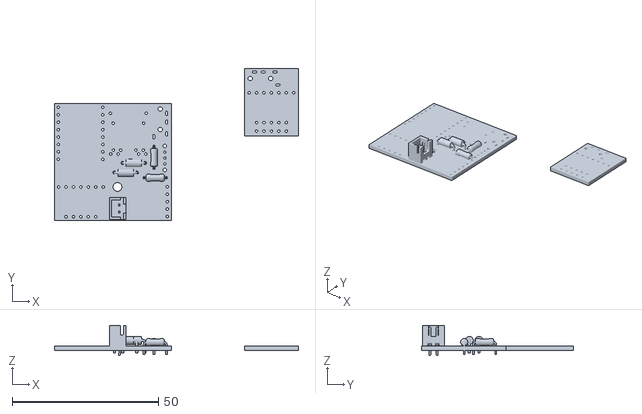
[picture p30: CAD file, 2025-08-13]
Schematic/Batt_804040/FBT2.stl
83.3 x 52.0 x 10.4

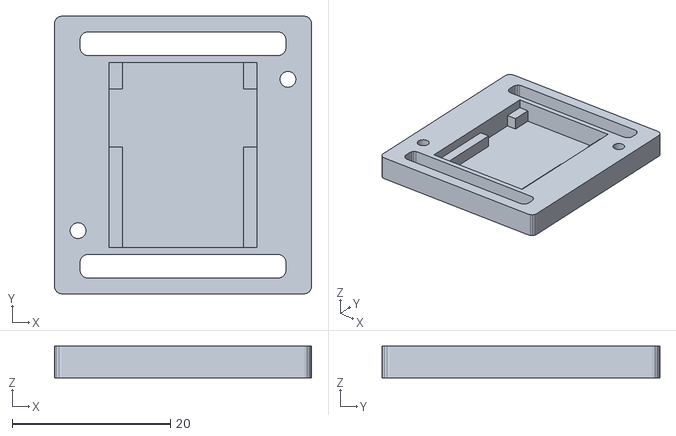
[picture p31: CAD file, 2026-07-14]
CAD/STL/ExtenderStrapLoop.stl
32.5 x 35.1 x 4.00

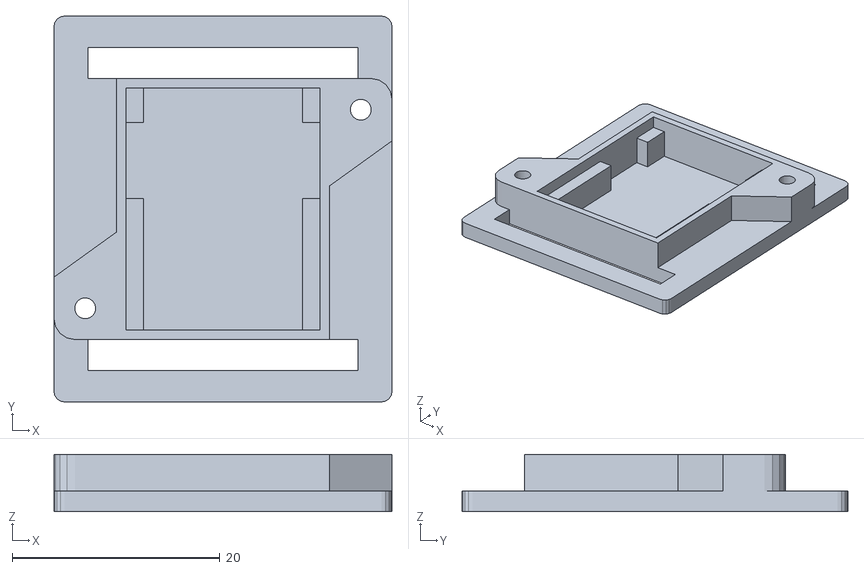
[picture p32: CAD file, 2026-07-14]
CAD/STL/Extender_v2_BasePlate.stl
32.5 x 37.1 x 5.50

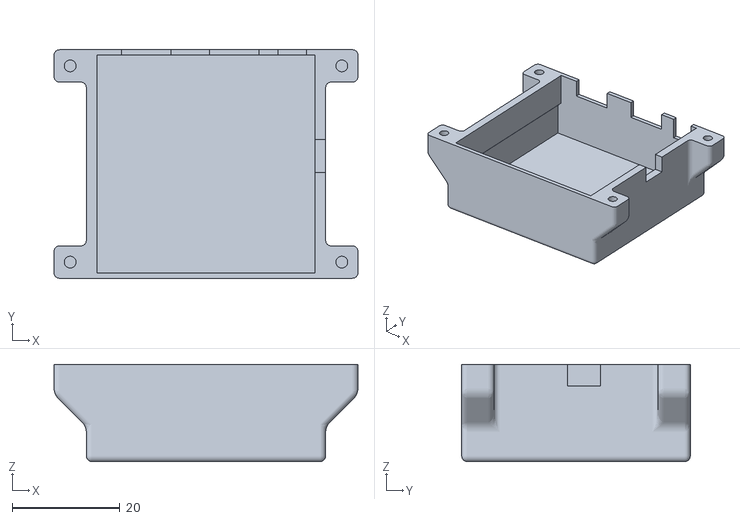
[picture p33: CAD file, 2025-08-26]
CAD/STL/Shell.stl
56.4 x 42.4 x 18.0

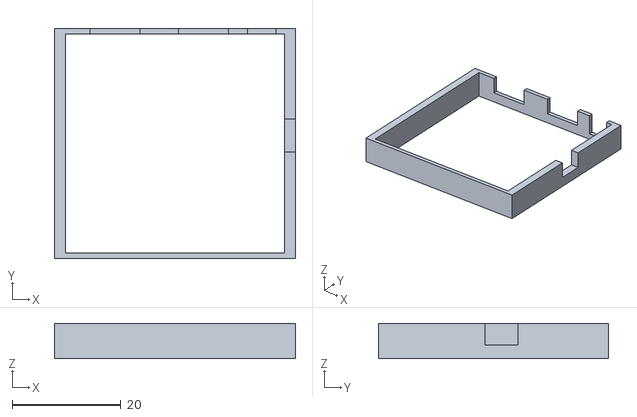
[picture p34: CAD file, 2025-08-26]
CAD/STL/ShellTest.stl
44.4 x 42.4 x 6.50

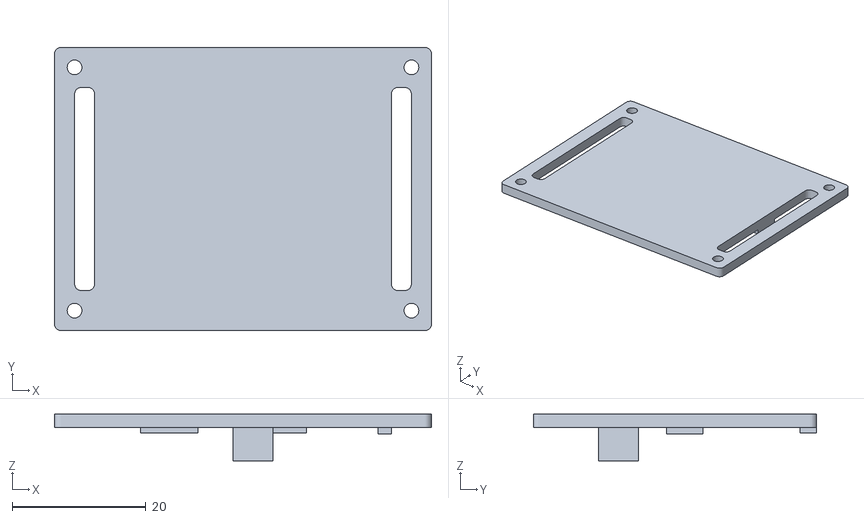
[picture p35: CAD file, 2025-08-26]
CAD/STL/StrapLoop.stl
56.4 x 42.4 x 7.00

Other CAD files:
CAD/STL/ExtenderShell.stl
CAD/Shell.blend
Reference/lxlbes_ref.blend

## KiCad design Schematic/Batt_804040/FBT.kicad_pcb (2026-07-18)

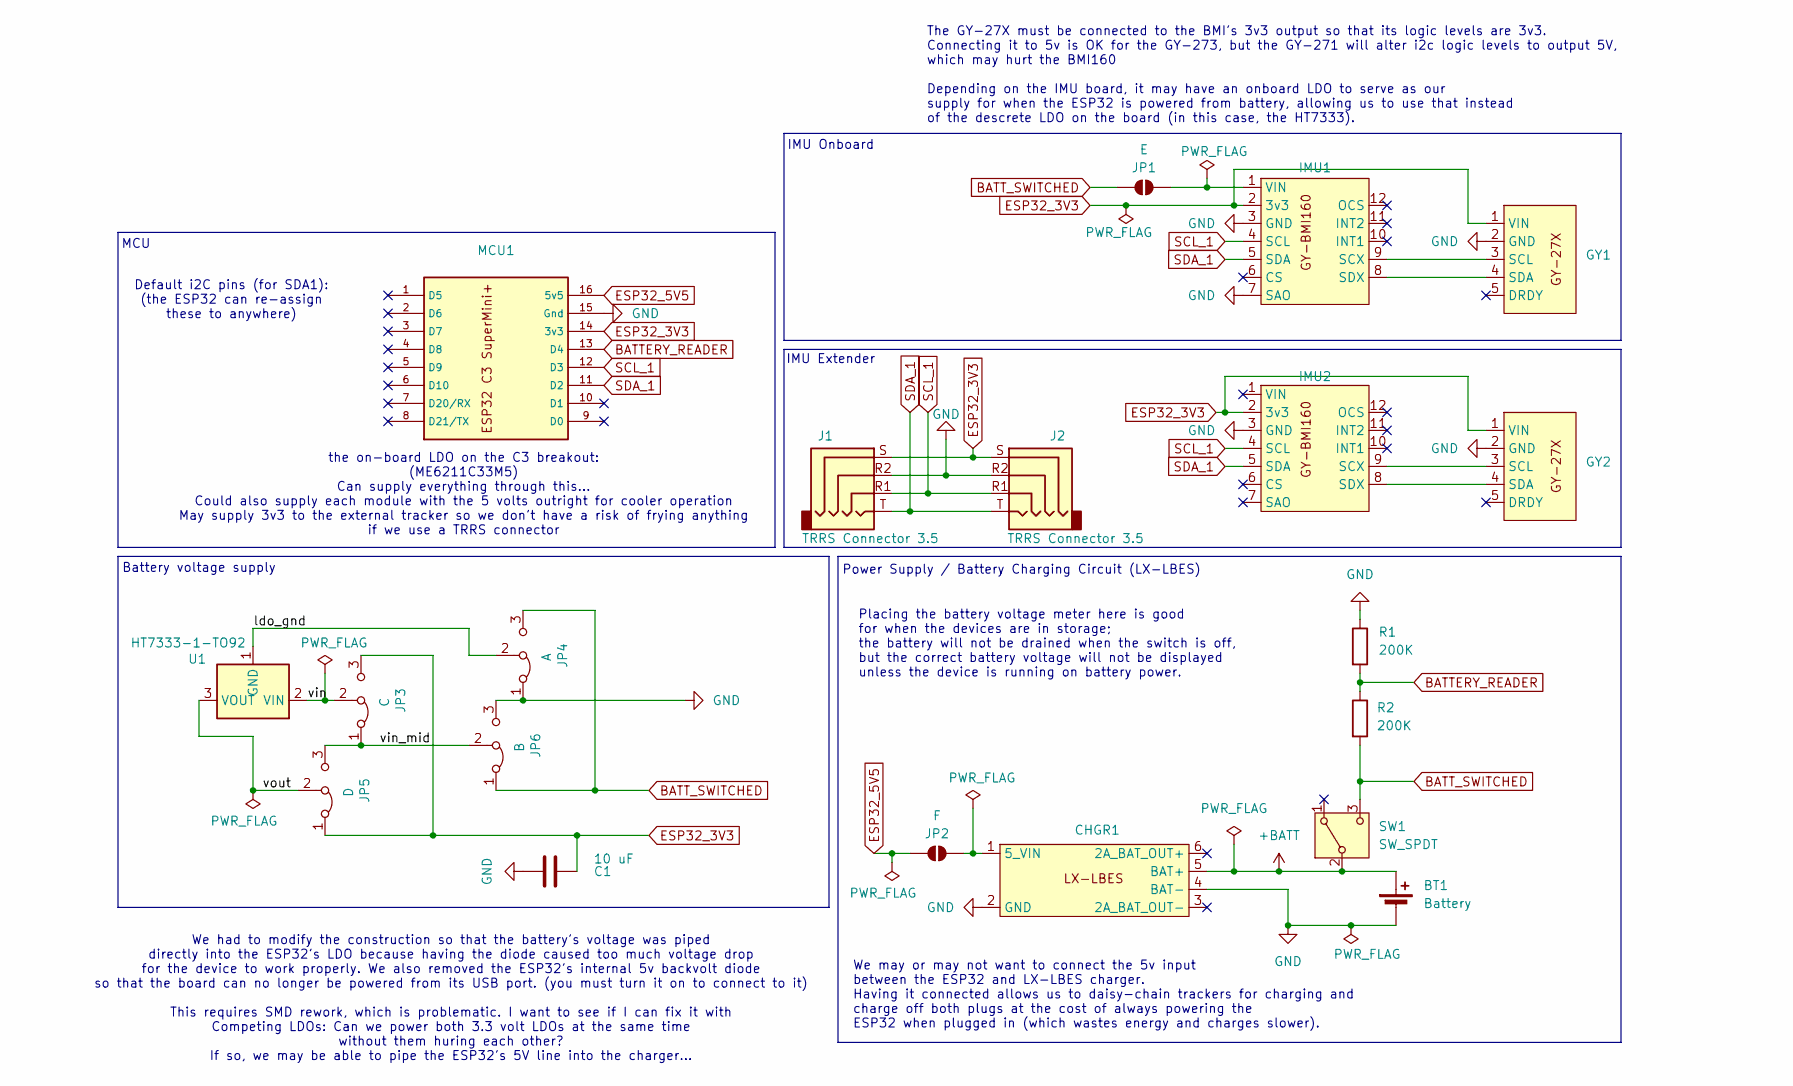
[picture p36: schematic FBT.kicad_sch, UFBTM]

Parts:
BT1: Battery; JST_XH_B2B-XH-A_1x02_P2.50mm_Vertical
C1: 10 uF; C_Disc_D5.0mm_W2.5mm_P5.00mm
CHGR1: LX_LBES
GY1, GY2: GY-271
IMU1, IMU2: GY-BMI160
J1, J2: TRRS Connector 3.5; PJ-320A
JP1: E; SolderJumper-2_P1.3mm_Open_RoundedPad1.0x1.5mm
JP2: F; SolderJumper-2_P1.3mm_Open_RoundedPad1.0x1.5mm
JP3: C; SolderJumper-3_P1.3mm_Bridged12_RoundedPad1.0x1.5mm_NumberL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
JP4: A; SolderJumper-3_P1.3mm_Bridged12_RoundedPad1.0x1.5mm_NumberL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
JP5: D; SolderJumper-3_P1.3mm_Bridged12_RoundedPad1.0x1.5mm_NumberL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
JP6: B; SolderJumper-3_P1.3mm_Bridged12_RoundedPad1.0x1.5mm_NumberL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
MCU1: ESP32-C3-SuperMini_PLUS
R1, R2: 200K; R_Axial_DIN0207_L6.3mm_D2.5mm_P7.62mm_Horizontal
SW1: SW_SPDT; SK12D07VG4
U1: HT7333-1-TO92; TO-92L_Inline

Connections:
+BATT: BT1.1 (+), CHGR1.5 (BAT+), SW1.2 (B); also elsewhere on the board
/ldo_gnd: JP4.2 (C), U1.1 (GND)
/vin: JP3.2 (C), U1.2 (VIN)
/vin_mid: JP3.1 (A), JP5.3 (B), JP6.2 (C)
/vout: JP5.2 (C), U1.3 (VOUT)
BATTERY_READER: MCU1.13 (D4), R1.2, R2.1
BATT_SWITCHED: JP1.2 (B), JP4.3 (B), JP6.1 (A), R2.2, SW1.3 (C)
ESP32_3V3: C1.1, GY1.1 (VIN), GY2.1 (VIN), IMU1.2 (3v3), IMU2.2 (3v3), J1.S, J2.S, JP3.3 (B), JP5.1 (A), MCU1.14 (3v3)
ESP32_5V5: JP2.2 (B), MCU1.16 (5v5)
GND: BT1.2 (-), C1.2, CHGR1.2 (GND), CHGR1.4 (BAT-), GY1.2 (GND), GY2.2 (GND), IMU1.3 (GND), IMU1.7 (SAO), IMU2.3 (GND), J1.R2, J2.R2, JP4.1 (A), JP6.3 (B), MCU1.15 (Gnd), R1.1; also elsewhere on the board
unnamed 10: CHGR1.1 (5_VIN), JP2.1 (A); also elsewhere on the board
unnamed: GY1.3 (SCL), IMU1.9 (SCX)
unnamed: GY1.4 (SDA), IMU1.8 (SDX)
unnamed: GY2.3 (SCL), IMU2.9 (SCX)
unnamed: GY2.4 (SDA), IMU2.8 (SDX)
unnamed: IMU1.1 (VIN), JP1.1 (A)
SCL_1: IMU1.4 (SCL), IMU2.4 (SCL), J1.R1, J2.R1, MCU1.12 (D3)
SDA_1: IMU1.5 (SDA), IMU2.5 (SDA), J1.T, J2.T, MCU1.11 (D2)

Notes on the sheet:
We may or may not want to connect the 5v input between the ESP32 and LX-LBES charger. Having it connected allows us to daisy-chain trackers for charging and charge off both plugs at the cost of always powering the ESP32 when plugged in (which wastes energy and charges slower).
IMU Extender
MCU
We had to modify the construction so that the battery's voltage was piped directly into the ESP32's LDO because having the diode caused too much voltage drop for the device to work properly. We also removed the ESP32's internal 5v backvolt diode so that the board can no longer be powered from its U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
Power Supply / Battery Charging Circuit (LX-LBES)
IMU Onboard
Placing the battery voltage meter here is good for when the devices are in storage; the battery will not be drained when the switch is off, but the correct battery voltage will not be displayed unless the device is running on battery power.
the on-board LDO on the C3 breakout: (ME6211C33M5) Can supply everything through this... Could also supply each module with the 5 volts outright for cooler operation May supply 3v3 to the external tracker so we don't have a risk of frying anything if we use a TRRS connector
Battery voltage supply
The GY-27X must be connected to the BMI's 3v3 output so that its logic levels are 3v3. Connecting it to 5v is OK for the GY-273, but the GY-271 will alter i2c logic levels to output 5V, which may hurt the BMI160 Depending on the IMU board, it may have an onboard LDO to serve as our supply for when 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
Default i2C pins (for SDA1): (the ESP32 can re-assign these to anywhere)

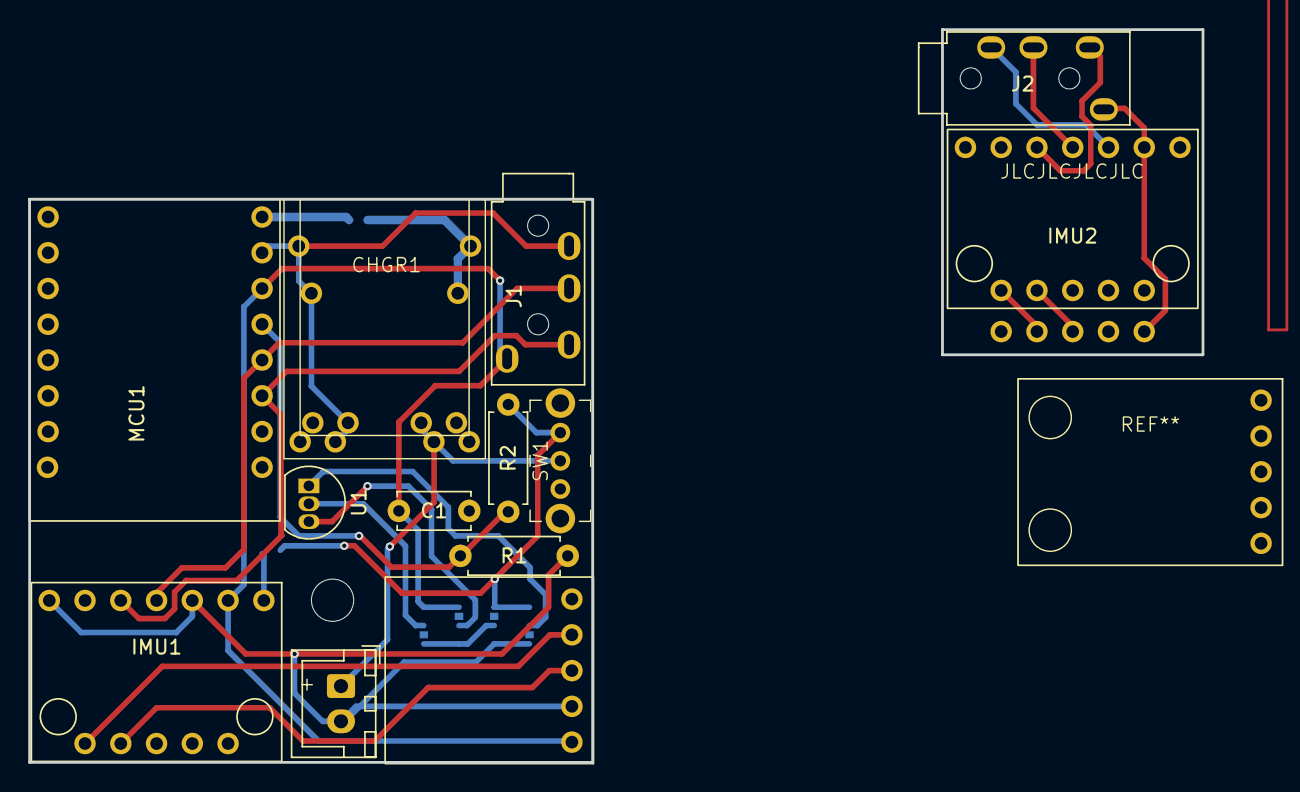
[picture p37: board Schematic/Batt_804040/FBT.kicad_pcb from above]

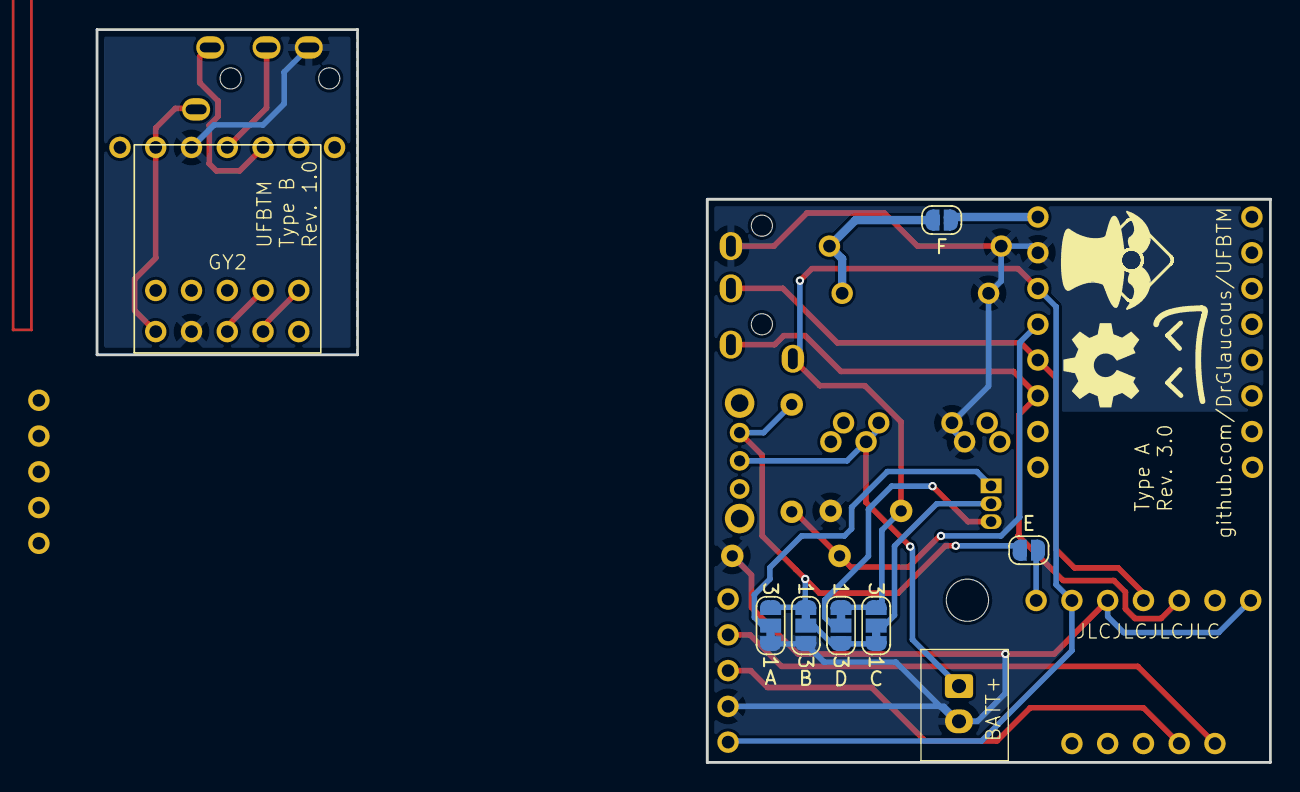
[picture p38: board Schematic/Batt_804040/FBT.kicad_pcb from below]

Board: 2 copper layers, 40.0 x 40.0 mm, 21 parts (7 on the bottom side), 18 nets.

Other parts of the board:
CHGR2: LX-LBES-Big

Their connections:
+BATT: CHGR2.5 (BAT+); also elsewhere on the board
GND: CHGR2.2 (GND), CHGR2.4 (BAT-); also elsewhere on the board
unnamed 10: CHGR2.1 (5_VIN); also elsewhere on the board

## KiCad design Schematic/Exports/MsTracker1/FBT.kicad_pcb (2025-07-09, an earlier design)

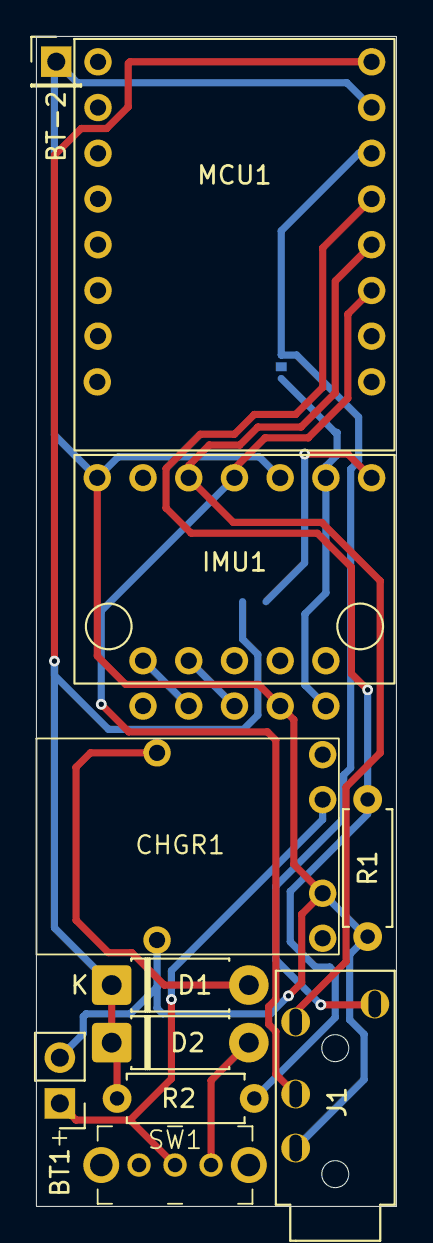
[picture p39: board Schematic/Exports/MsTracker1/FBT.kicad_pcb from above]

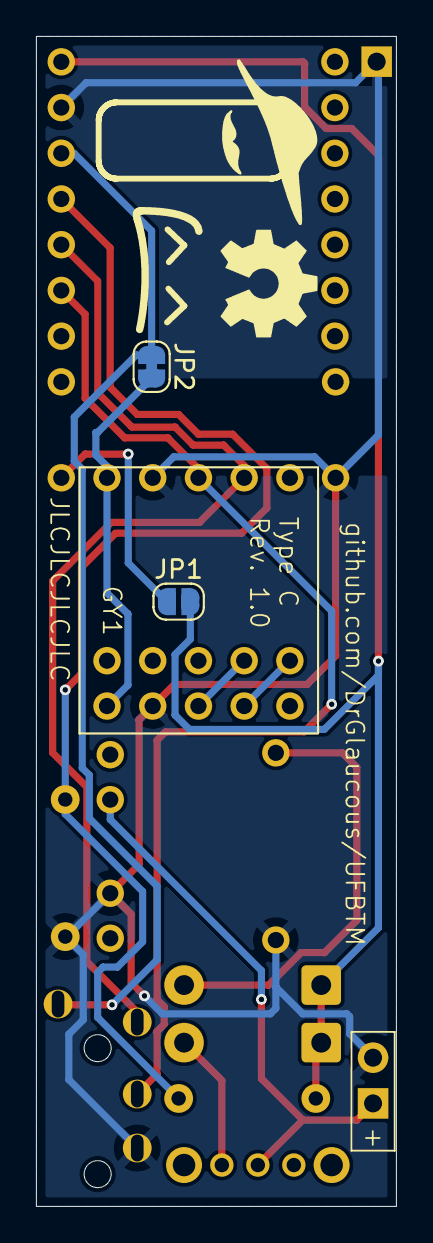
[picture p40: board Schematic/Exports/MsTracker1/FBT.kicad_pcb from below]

Board: 2 copper layers, 20.0 x 65.0 mm, 14 parts (3 on the bottom side), 13 nets.

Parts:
BT1: Battery; PinHeader_1x02_P2.54mm_Vertical
BT-2: Battery anode; PinHeader_1x01_P2.54mm_Vertical
CHGR1: LX_LBES
D1: D_1N5817 / 4.8v Zener?; D_DO-41_SOD81_P7.62mm_Horizontal
D2: D_1N5817; D_DO-41_SOD81_P7.62mm_Horizontal
GY1: GY-271
IMU1: GY-BMI160
J1: TRRS Connector 3.5; PJ-320A
JP1: 5v in; SolderJumper-2_P1.3mm_Open_RoundedPad1.0x1.5mm
JP2: 3v3 in; SolderJumper-2_P1.3mm_Bridged_RoundedPad1.0x1.5mm
MCU1: ESP32-C3-SuperMini_PLUS
R1, R2: 200K; R_Axial_DIN0207_L6.3mm_D2.5mm_P7.62mm_Horizontal
SW1: SW_SPDT; SK12D07VG4

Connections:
+BATT: BT1.1 (+), CHGR1.5 (BAT+), SW1.2 (B)
BATTERY_READER: MCU1.13 (D4), R1.2, R2.1
ESP32_3V3: J1.T, JP2.1 (A), MCU1.14 (3v3)
ESP32_5V5: D1.1 (K), D2.1 (K), JP1.2 (B), MCU1.16 (5v5), R2.2
GND: BT1.2 (-), BT-2.1, CHGR1.2 (GND), CHGR1.4 (BAT-), GY1.2 (GND), IMU1.3 (GND), IMU1.7 (SAO), J1.S, MCU1.15 (Gnd), R1.1
unnamed: CHGR1.1 (5_VIN), D1.2 (A)
unnamed: D2.2 (A), SW1.3 (C)
unnamed: GY1.3 (SCL), IMU1.9 (SCX)
unnamed: GY1.4 (SDA), IMU1.8 (SDX)
unnamed: GY1.1 (VIN), IMU1.2 (3v3), JP2.2 (B)
unnamed: IMU1.1 (VIN), JP1.1 (A)
SCL_1: IMU1.4 (SCL), J1.R2, MCU1.11 (D2)
SDA_1: IMU1.5 (SDA), J1.R1, MCU1.12 (D3)

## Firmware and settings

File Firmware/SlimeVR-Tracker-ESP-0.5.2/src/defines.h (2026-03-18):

/*
	SlimeVR Code is placed under the MIT license
	Copyright (c) 2021 Eiren Rain

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
	THE SOFTWARE IS PROVIDED "AS IS", WITHOUT WARRANTY OF ANY KIND, EXPRESS OR
	IMPLIED, INCLUDING BUT NOT LIMITED TO THE WARRANTIES OF MERCHANTABILITY,
	FITNESS FOR A PARTICULAR PURPOSE AND NONINFRINGEMENT. IN NO EVENT SHALL THE
	AUTHORS OR COPYRIGHT HOLDERS BE LIABLE FOR ANY CLAIM, DAMAGES OR OTHER
	LIABILITY, WHETHER IN AN ACTION OF CONTRACT, TORT OR OTHERWISE, ARISING FROM,
	OUT OF OR IN CONNECTION WITH THE SOFTWARE OR THE USE OR OTHER DEALINGS IN
	THE SOFTWARE.
*/
// ================================================
// See docs for configuration options and examples:
// https://docs.slimevr.dev/firmware/configuring-project.html#2-configuring-definesh
// ================================================

// Set parameters of IMU and board used
#define IMU IMU_LSM6DS3
#define SECOND_IMU IMU_BMI160
#define BOARD BOARD_LOLIN_C3_MINI
#define IMU_ROTATION DEG_270
#define SECOND_IMU_ROTATION DEG_0

#define PRIMARY_IMU_OPTIONAL false
#define SECONDARY_IMU_OPTIONAL true

#define MAX_IMU_COUNT 2


#include "sensors/axisremap.h"
// #define BMI160_AXIS_REMAP_PRIMARY AXIS_REMAP_BUILD( \
//   AXIS_REMAP_USE_X, \
//   AXIS_REMAP_USE_YN, \
//   AXIS_REMAP_USE_ZN, \
//   \
// 	AXIS_REMAP_USE_X, \
// 	AXIS_REMAP_USE_Y, \
// 	AXIS_REMAP_USE_ZN  \
// )



//for testing
#define BMI160_AXIS_REMAP_PRIMARY AXIS_REMAP_BUILD( \
  AXIS_REMAP_USE_X, \
  AXIS_REMAP_USE_Y, \
  AXIS_REMAP_USE_Z, \
  \
	AXIS_REMAP_USE_X, \
	AXIS_REMAP_USE_Y, \
	AXIS_REMAP_USE_Z  \
)



//SECONDARY
#define BMI160_AXIS_REMAP_SECONDARY AXIS_REMAP_BUILD( \
  AXIS_REMAP_USE_X, \
  AXIS_REMAP_USE_Y, \
  AXIS_REMAP_USE_Z, \
  \
	AXIS_REMAP_USE_Y, \
	AXIS_REMAP_USE_XN, \
	AXIS_REMAP_USE_Z  \
)

// Axis mapping example
/*
#include "sensors/axisremap.h"
#define BMI160_QMC_REMAP AXIS_REMAP_BUILD(AXIS_REMAP_USE_Y, AXIS_REMAP_USE_XN,
AXIS_REMAP_USE_Z, \ AXIS_REMAP_USE_YN, AXIS_REMAP_USE_X, AXIS_REMAP_USE_Z)

IMU_DESC_ENTRY(IMU_BMP160, PRIMARY_IMU_ADDRESS_ONE, IMU_ROTATION, PIN_IMU_SCL,
PIN_IMU_SDA, PRIMARY_IMU_OPTIONAL, BMI160_QMC_REMAP) \
*/

#ifndef IMU_DESC_LIST
#define IMU_DESC_LIST              \
	IMU_DESC_ENTRY(                \
		IMU,                       \
		PRIMARY_IMU_ADDRESS_ONE,   \
		IMU_ROTATION,              \
		PIN_IMU_SCL,               \
		PIN_IMU_SDA,               \
		PRIMARY_IMU_OPTIONAL,      \
		BMI160_AXIS_REMAP_PRIMARY  \
	)                              \
	IMU_DESC_ENTRY(                \
		SECOND_IMU,                \
		SECONDARY_IMU_ADDRESS_TWO, \
		SECOND_IMU_ROTATION,       \
		PIN_IMU_SCL,               \
		PIN_IMU_SDA,               \
		SECONDARY_IMU_OPTIONAL,    \
		BMI160_AXIS_REMAP_SECONDARY\
	)
#endif

// Battery monitoring options (comment to disable):
//   BAT_EXTERNAL for ADC pin,
//   BAT_INTERNAL for internal - can detect only low battery,
//   BAT_MCP3021 for external ADC connected over I2C
#define BATTERY_MONITOR BAT_EXTERNAL

// BAT_EXTERNAL definition override
// D1 Mini boards with ESP8266 have internal resistors. For these boards you only have
// to adjust BATTERY_SHIELD_RESISTANCE. For other boards you can now adjust the other
// resistor values. The diagram looks like this:
//   (Battery)--- [BATTERY_SHIELD_RESISTANCE] ---(INPUT_BOARD)---  [BATTERY_SHIELD_R2]
//   ---(ESP32_INPUT)--- [BATTERY_SHIELD_R1] --- (GND)
// #define BATTERY_SHIELD_RESISTANCE 180 //130k BatteryShield, 180k SlimeVR or fill in
// external resistor value in kOhm #define BATTERY_SHIELD_R1 100 // Board voltage
// divider resistor Ain to GND in kOhm #define BATTERY_SHIELD_R2 220 // Board voltage
// divider resistor Ain to INPUT_BOARD in kOhm

// LED configuration:
// Configuration Priority 1 = Highest:
// 1. LED_PIN
// 2. LED_BUILTIN
//
//   LED_PIN
//     - Number or Symbol (D1,..) of the Output
//     - To turn off the LED, set LED_PIN to LED_OFF
//   LED_INVERTED
//     - false for output 3.3V on high
//     - true for pull down to GND on high
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

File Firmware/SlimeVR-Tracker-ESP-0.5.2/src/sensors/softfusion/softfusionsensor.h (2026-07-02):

/*
	SlimeVR Code is placed under the MIT license
	Copyright (c) 2024 Tailsy13 & SlimeVR Contributors

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
	THE SOFTWARE IS PROVIDED "AS IS", WITHOUT WARRANTY OF ANY KIND, EXPRESS OR
	IMPLIED, INCLUDING BUT NOT LIMITED TO THE WARRANTIES OF MERCHANTABILITY,
	FITNESS FOR A PARTICULAR PURPOSE AND NONINFRINGEMENT. IN NO EVENT SHALL THE
	AUTHORS OR COPYRIGHT HOLDERS BE LIABLE FOR ANY CLAIM, DAMAGES OR OTHER
	LIABILITY, WHETHER IN AN ACTION OF CONTRACT, TORT OR OTHERWISE, ARISING FROM,
	OUT OF OR IN CONNECTION WITH THE SOFTWARE OR THE USE OR OTHER DEALINGS IN
	THE SOFTWARE.
*/

#pragma once

#include "../SensorFusionRestDetect.h"
#include "../sensor.h"
#include "GlobalVars.h"

namespace SlimeVR::Sensors {

template <template <typename I2CImpl> typename T, typename I2CImpl>
class SoftFusionSensor : public Sensor {
	using imu = T<I2CImpl>;
	using RawVectorT = std::array<int16_t, 3>;
	static constexpr auto UpsideDownCalibrationInit = true;
	static constexpr auto GyroCalibDelaySeconds = 5;
	static constexpr auto GyroCalibSeconds = 5;
	static constexpr auto SampleRateCalibDelaySeconds = 1;
	static constexpr auto SampleRateCalibSeconds = 5;

	static constexpr auto AccelCalibDelaySeconds = 3;
	static constexpr auto AccelCalibRestSeconds = 3;

	static constexpr double GScale
		= ((32768. / imu::GyroSensitivity) / 32768.) * (PI / 180.0);
	static constexpr double AScale = CONST_EARTH_GRAVITY / imu::AccelSensitivity;

	static constexpr bool HasMotionlessCalib
		= requires(imu& i) { typename imu::MotionlessCalibrationData; };
	static constexpr size_t MotionlessCalibDataSize() {
		if constexpr (HasMotionlessCalib) {
			return sizeof(typename imu::MotionlessCalibrationData);
		} else {
			return 0;
		}
	}

	//doesn't need to be in the sub-class
	int axisRemap;

	//check the sensor status at the whoami register
	bool detected() const {
		const auto value = m_sensor.i2c.readReg(imu::Regs::WhoAmI::reg);
		if (imu::Regs::WhoAmI::value != value) {
			m_Logger.error(
				"Sensor not detected, expected reg 0x%02x = 0x%02x but got 0x%02x",
				imu::Regs::WhoAmI::reg,
				imu::Regs::WhoAmI::value,
				value
			);
			return false;
		}

		return true;
	}

	void sendTempIfNeeded() {
		uint32_t now = micros();
		constexpr float maxSendRateHz = 2.0f;
		constexpr uint32_t sendInterval = 1.0f / maxSendRateHz * 1e6;
		uint32_t elapsed = now - m_lastTemperaturePacketSent;
		if (elapsed >= sendInterval) {
			const float temperature = m_sensor.getDirectTemp();
			m_lastTemperaturePacketSent = now - (elapsed - sendInterval);
			networkConnection.sendTemperature(sensorId, temperature);
		}
	}

	//tell the gyro accelerometer magnetometer combiner to... create a new fusion object?
	void recalcFusion() {
		m_fusion = SensorFusionRestDetect(
			m_calibration.G_Ts,
			m_calibration.A_Ts,
			m_calibration.M_Ts
		);
	}

	//take our axis values, apply temperature offset to them, and then update the m_fusion with that.
	void processAccelSample(const int16_t xyz[3], const sensor_real_t timeDelta) {
		sensor_real_t accelData[]
			= {static_cast<sensor_real_t>(xyz[0]),
			   static_cast<sensor_real_t>(xyz[1]),
			   static_cast<sensor_real_t>(xyz[2])};

		float tmp[3];
		for (uint8_t i = 0; i < 3; i++) {
			tmp[i] = (accelData[i] - m_calibration.A_B[i]);
		}

		accelData[0]
			= (m_calibration.A_Ainv[0][0] * tmp[0] + m_calibration.A_Ainv[0][1] * tmp[1]
			   + m_calibration.A_Ainv[0][2] * tmp[2])
			* AScale;
		accelData[1]
			= (m_calibration.A_Ainv[1][0] * tmp[0] + m_calibration.A_Ainv[1][1] * tmp[1]
			   + m_calibration.A_Ainv[1][2] * tmp[2])
			* AScale;
		accelData[2]
			= (m_calibration.A_Ainv[2][0] * tmp[0] + m_calibration.A_Ainv[2][1] * tmp[1]
			   + m_calibration.A_Ainv[2][2] * tmp[2])
			* AScale;

		//remap
		remapAllAxis(AXIS_REMAP_GET_ALL_IMU(axisRemap), &accelData[0], &accelData[1], &accelData[2]);


		m_fusion.updateAcc(accelData, m_calibration.A_Ts);
	}

	//ditto, but for gyroscope
	void processGyroSample(const int16_t xyz[3], const sensor_real_t timeDelta) {

		//apply scale
		sensor_real_t gyroData[] = {
			static_cast<sensor_real_t>(
				GScale * (static_cast<sensor_real_t>(xyz[0]) - m_calibration.G_off[0])
			),
			static_cast<sensor_real_t>(
				GScale * (static_cast<sensor_real_t>(xyz[1]) - m_calibration.G_off[1])
			),
			static_cast<sensor_real_t>(
				GScale * (static_cast<sensor_real_t>(xyz[2]) - m_calibration.G_off[2])
			)
		};

		//apply tempcal (todo: add this, see: bmi160sensor.cpp)


		//remap (why wasn't this already here?!)
		remapAllAxis(AXIS_REMAP_GET_ALL_IMU(axisRemap), &gyroData[0], &gyroData[1], &gyroData[2]);


		m_fusion.updateGyro(gyroData, m_calibration.G_Ts);
	}

	//new: process magnetometer data now
	void processMagSample(const int16_t xyz[3], const sensor_real_t timeDelta) {

		if(m_calibration.magEnabled == false) {
			return;
		}


		//apply calibration offsets
		sensor_real_t magData[]
			= {static_cast<sensor_real_t>(xyz[0]),
			   static_cast<sensor_real_t>(xyz[1]),
			   static_cast<sensor_real_t>(xyz[2])};

		

		//Serial.printf("  Pre Mag : %6f, %6f, %6f\n", magData[0 + 0], magData[0 + 1], magData[0 + 2]);

		float tmp[3];
		for (uint8_t i = 0; i < 3; i++) {
			tmp[i] = (magData[i] - m_calibration.M_B[i]);
		}

		magData[0] = m_calibration.M_Ainv[0][0] * tmp[0] + m_calibration.M_Ainv[0][1] * tmp[1]
			       + m_calibration.M_Ainv[0][2] * tmp[2];
		magData[1] = m_calibration.M_Ainv[1][0] * tmp[0] + m_calibration.M_Ainv[1][1] * tmp[1]
			       + m_calibration.M_Ainv[1][2] * tmp[2];
		magData[2] = m_calibration.M_Ainv[2][0] * tmp[0] + m_calibration.M_Ainv[2][1] * tmp[1]
			       + m_calibration.M_Ainv[2][2] * tmp[2];

		//remap
		remapAllAxis(AXIS_REMAP_GET_ALL_MAG(axisRemap), &magData[0], &magData[1], &magData[2]);

		//Serial.printf("Mag: %6f, %6f, %6f\n", magData[0 + 0], magData[0 + 1], magData[0 + 2]);

		//update the sensor fusion
		m_fusion.updateMag(magData, m_calibration.M_Ts);
	}



	//block for X seconds and pull all the sample data into dummy variables
	void eatSamplesForSeconds(const uint32_t seconds) {
		const auto targetDelay = millis() + 1000 * seconds;
		auto lastSecondsRemaining = seconds;
		while (millis() < targetDelay) {
#ifdef ESP8266
			ESP.wdtFeed(); //ensure the dog is fed while we're stuck in this while loop
#endif
			//log every second passed
			auto currentSecondsRemaining = (targetDelay - millis()) / 1000;
			if (currentSecondsRemaining != lastSecondsRemaining) {
				m_Logger.info("%d...", currentSecondsRemaining + 1);
				lastSecondsRemaining = currentSecondsRemaining;
			}
			m_sensor.bulkRead(
				[](const int16_t xyz[3], const sensor_real_t timeDelta) {},
				[](const int16_t xyz[3], const sensor_real_t timeDelta) {},
				[](const int16_t xyz[3], const sensor_real_t timeDelta) {}
			);
		}
	}
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

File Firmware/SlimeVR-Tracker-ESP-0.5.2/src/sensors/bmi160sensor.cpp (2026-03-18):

/*
	SlimeVR Code is placed under the MIT license
	Copyright (c) 2021 S.J. Remington & SlimeVR contributors

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
	THE SOFTWARE IS PROVIDED "AS IS", WITHOUT WARRANTY OF ANY KIND, EXPRESS OR
	IMPLIED, INCLUDING BUT NOT LIMITED TO THE WARRANTIES OF MERCHANTABILITY,
	FITNESS FOR A PARTICULAR PURPOSE AND NONINFRINGEMENT. IN NO EVENT SHALL THE
	AUTHORS OR COPYRIGHT HOLDERS BE LIABLE FOR ANY CLAIM, DAMAGES OR OTHER
	LIABILITY, WHETHER IN AN ACTION OF CONTRACT, TORT OR OTHERWISE, ARISING FROM,
	OUT OF OR IN CONNECTION WITH THE SOFTWARE OR THE USE OR OTHER DEALINGS IN
	THE SOFTWARE.
*/

#include "bmi160sensor.h"

//test: get external sensor offsetting
//#include "../serial/serialcommands.h"

#include <hmc5883l.h>
#include <qmc5883l.h>
#include <qmc5883p.h>

#include <map>

#include "GlobalVars.h"

void BMI160Sensor::initHMC(BMI160MagRate magRate) {
	/* Configure MAG interface and setup mode */
	/* Set MAG interface normal power mode */
	imu.setRegister(BMI160_RA_CMD, BMI160_CMD_MAG_MODE_NORMAL);
	delay(60);

	/* Enable MAG interface */
	imu.setRegister(BMI160_RA_IF_CONF, BMI160_IF_CONF_MODE_PRI_AUTO_SEC_MAG);
	delay(1);

	imu.setMagDeviceAddress(HMC_DEVADDR);
	delay(3);
	imu.setRegister(BMI160_RA_MAG_IF_1_MODE, BMI160_MAG_SETUP_MODE);
	delay(3);

	/* Configure HMC5883L Sensor */
	imu.setMagRegister(
		HMC_RA_CFGA,
		HMC_CFGA_DATA_RATE_75 | HMC_CFGA_AVG_SAMPLES_8 | HMC_CFGA_BIAS_NORMAL
	);
	imu.setMagRegister(HMC_RA_CFGB, HMC_CFGB_GAIN_1_30);
	imu.setMagRegister(HMC_RA_MODE, HMC_MODE_HIGHSPEED | HMC_MODE_READ_CONTINUOUS);

	imu.setRegister(BMI160_RA_MAG_IF_2_READ_RA, HMC_RA_DATA);
	imu.setRegister(BMI160_RA_MAG_CONF, magRate);
	delay(3);
	imu.setRegister(BMI160_RA_MAG_IF_1_MODE, BMI160_MAG_DATA_MODE_6);
}

void BMI160Sensor::initQMC(BMI160MagRate magRate) {
	/* Configure MAG interface and setup mode */
	/* Set MAG interface normal power mode */
	imu.setRegister(BMI160_RA_CMD, BMI160_CMD_MAG_MODE_NORMAL);
	delay(60);

	/* Enable MAG interface */
	imu.setRegister(BMI160_RA_IF_CONF, BMI160_IF_CONF_MODE_PRI_AUTO_SEC_MAG);
	delay(1);

	imu.setMagDeviceAddress(QMC_DEVADDR);
	delay(3);
	imu.setRegister(BMI160_RA_MAG_IF_1_MODE, BMI160_MAG_SETUP_MODE);
	delay(3);

	/* Configure QMC5883L Sensor */
	imu.setMagRegister(QMC_RA_RESET, 1);
	delay(3);
	imu.setMagRegister(
		QMC_RA_CONTROL,
		QMC_CFG_MODE_CONTINUOUS | QMC_CFG_ODR_200HZ | QMC_CFG_RNG_8G | QMC_CFG_OSR_512
	);

	imu.setRegister(BMI160_RA_MAG_IF_2_READ_RA, QMC_RA_DATA);
	imu.setRegister(BMI160_RA_MAG_CONF, magRate);
	delay(3);
	imu.setRegister(BMI160_RA_MAG_IF_1_MODE, BMI160_MAG_DATA_MODE_6);
}

void BMI160Sensor::initQMP(BMI160MagRate magRate) {
	/* Configure MAG interface and setup mode */
	/* Set MAG interface normal power mode */
	imu.setRegister(BMI160_RA_CMD, BMI160_CMD_MAG_MODE_NORMAL);
	delay(60);

	/* Enable MAG interface */
	imu.setRegister(BMI160_RA_IF_CONF, BMI160_IF_CONF_MODE_PRI_AUTO_SEC_MAG);
	delay(1);

	imu.setMagDeviceAddress(QMP_DEVADDR);
	delay(3);
	imu.setRegister(BMI160_RA_MAG_IF_1_MODE, BMI160_MAG_SETUP_MODE);
	delay(3);

	/* Configure QMC5883P Sensor */
	imu.setMagRegister(
		QMP_RA_CONTROL,
		QMP_CFG_MODE_CONT | QMP_CFG_ODR_200HZ | QMP_CFG_OVR_SMPL8 | QMP_CFG_DOWN_SMPL8
	);
	delay(3);
	imu.setMagRegister(
		QMP_RA_CONTROL2,
		QMP_CFG_RNG_8G
	);
	delay(3);


	imu.setRegister(BMI160_RA_MAG_IF_2_READ_RA, QMP_RA_DATA);
	imu.setRegister(BMI160_RA_MAG_CONF, magRate);
	delay(3);
	imu.setRegister(BMI160_RA_MAG_IF_1_MODE, BMI160_MAG_DATA_MODE_6);
}




void BMI160Sensor::motionSetup() {


	// Initialize the configuration from persistent settings, must be done here because we use magStatus below.
	{
		SlimeVR::Configuration::SensorConfig sensorConfig
			= configuration.getSensor(sensorId);
		// If no compatible calibration data is found, the calibration data will just be zeroed out
		switch (sensorConfig.type) {
			case SlimeVR::Configuration::SensorConfigType::BMI160:
				m_Config = sensorConfig.data.bmi160;

				magStatus = m_Config.magEnabled ? MagnetometerStatus::MAG_ENABLED
												: MagnetometerStatus::MAG_DISABLED;

				break;

			case SlimeVR::Configuration::SensorConfigType::NONE:

				//if not preset, use factory value to determine mag status
				magStatus = USE_6_AXIS ? MagnetometerStatus::MAG_DISABLED
									: MagnetometerStatus::MAG_ENABLED;

				m_Logger.warn(
					"No calibration data found for sensor %d, ignoring...",
					sensorId
				);
				m_Logger.info("Calibration is advised");
				break;

			default:
				//see above
				magStatus = USE_6_AXIS ? MagnetometerStatus::MAG_DISABLED
									: MagnetometerStatus::MAG_ENABLED;

				m_Logger.warn(
					"Incompatible calibration data found for sensor %d, ignoring...",
					sensorId
				);
				m_Logger.info("Calibration is advised");
		}
	}


	//initialize the re-defined constexpr vars and preprocessor variables that change when we enable / disable the magnetometer
	{

		this->BMI160_GYRO_RATE = (magStatus == MagnetometerStatus::MAG_ENABLED) ? BMI160_GYRO_RATE_9 : BMI160_GYRO_RATE_6;


		this->BMI160_ODR_GYR_HZ = 25.0f * (1 << (BMI160_GYRO_RATE - 6));
		this->BMI160_ODR_ACC_HZ = 12.5f * (1 << (BMI160_ACCEL_RATE - 5));


		this->BMI160_ODR_GYR_MICROS
		= BMI160_MAP_ODR_MICROS(1.0f / BMI160_ODR_GYR_HZ * 1e6f);

		this->BMI160_ODR_ACC_MICROS
		= BMI160_MAP_ODR_MICROS(1.0f / BMI160_ODR_ACC_HZ * 1e6f);

		// note: this value only sets polling and fusion update rate - HMC is internally sampled
		// at 75hz, QMC at 200hz
		if(magStatus == MagnetometerStatus::MAG_ENABLED) {
			this->BMI160_ODR_MAG_HZ = 0;
			this->BMI160_ODR_MAG_MICROS = 0;
		} else {
			this->BMI160_ODR_MAG_HZ = (25.0f / 32.0f) * (1 << (BMI160_MAG_RATE - 1));
			this->BMI160_ODR_MAG_MICROS
				= BMI160_MAP_ODR_MICROS(1.0f / BMI160_ODR_MAG_HZ * 1e6f);
		}



		this->BMI160_SETTINGS_MAX_ODR_HZ
			= max(max(BMI160_ODR_GYR_HZ, BMI160_ODR_ACC_HZ), BMI160_ODR_MAG_HZ);
		this->BMI160_SETTINGS_MAX_ODR_MICROS
			= BMI160_MAP_ODR_MICROS(1.0f / BMI160_SETTINGS_MAX_ODR_HZ * 1e6f);

		this->BMI160_FIFO_AVG_DATA_FRAME_LENGTH
			= (BMI160_SETTINGS_MAX_ODR_HZ * 1 + BMI160_ODR_GYR_HZ * BMI160_FIFO_G_LEN
			+ BMI160_ODR_ACC_HZ * BMI160_FIFO_A_LEN + BMI160_ODR_MAG_HZ * BMI160_FIFO_M_LEN)
			/ BMI160_SETTINGS_MAX_ODR_HZ;


		this->BMI160_FIFO_READ_BUFFER_SIZE_SAMPLES
			= BMI160_SETTINGS_MAX_ODR_HZ * BMI160_FIFO_READ_BUFFER_SIZE_MICROS / 1e6f;


		this->BMI160_FIFO_READ_BUFFER_SIZE_BYTES = min(
			(float)BMI160_FIFO_MAX_LENGTH - 64,
			BMI160_FIFO_READ_BUFFER_SIZE_SAMPLES* BMI160_FIFO_AVG_DATA_FRAME_LENGTH * 1.25f
		);
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

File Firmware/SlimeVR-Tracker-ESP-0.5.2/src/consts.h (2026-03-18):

/*
	SlimeVR Code is placed under the MIT license
	Copyright (c) 2021 Eiren Rain & SlimeVR contributors

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
	THE SOFTWARE IS PROVIDED "AS IS", WITHOUT WARRANTY OF ANY KIND, EXPRESS OR
	IMPLIED, INCLUDING BUT NOT LIMITED TO THE WARRANTIES OF MERCHANTABILITY,
	FITNESS FOR A PARTICULAR PURPOSE AND NONINFRINGEMENT. IN NO EVENT SHALL THE
	AUTHORS OR COPYRIGHT HOLDERS BE LIABLE FOR ANY CLAIM, DAMAGES OR OTHER
	LIABILITY, WHETHER IN AN ACTION OF CONTRACT, TORT OR OTHERWISE, ARISING FROM,
	OUT OF OR IN CONNECTION WITH THE SOFTWARE OR THE USE OR OTHER DEALINGS IN
	THE SOFTWARE.
*/
#ifndef SLIMEVR_CONSTS_H_
#define SLIMEVR_CONSTS_H_

// List of constants used in other places

enum class ImuID {
	Unknown = 0,
	MPU9250,
	MPU6500,
	BNO080,
	BNO085,
	BNO055,
	MPU6050,
	BNO086,
	BMI160,
	ICM20948,
	ICM42688,
	BMI270,
	LSM6DS3TRC,
	LSM6DSV,
	LSM6DSO,
	LSM6DSR,
	ICM45686,
	ICM45605,
	ADC_RESISTANCE,
	LSM6DS3,
	Empty = 255
};

#define IMU_UNKNOWN ErroneousSensor
#define IMU_MPU9250 MPU9250Sensor
#define IMU_MPU6500 MPU6050Sensor
#define IMU_BNO080 BNO080Sensor
#define IMU_BNO085 BNO085Sensor
#define IMU_BNO055 BNO055Sensor
#define IMU_MPU6050 MPU6050Sensor
#define IMU_BNO086 BNO086Sensor
#define IMU_BMI160 BMI160Sensor
#define IMU_ICM20948 ICM20948Sensor
#define IMU_ICM42688 SoftFusionICM42688
#define IMU_BMI270 SoftFusionBMI270
#define IMU_LSM6DS3 SoftFusionLSM6DS3
#define IMU_LSM6DS3TRC SoftFusionLSM6DS3TRC
#define IMU_LSM6DSV SoftFusionLSM6DSV
#define IMU_LSM6DSO SoftFusionLSM6DSO
#define IMU_LSM6DSR SoftFusionLSM6DSR
#define IMU_MPU6050_SF SoftFusionMPU6050

#define IMU_DEV_RESERVED 250  // Reserved, should not be used in any release firmware

#define BOARD_UNKNOWN 0
#define BOARD_SLIMEVR_LEGACY 1
#define BOARD_SLIMEVR_DEV 2
#define BOARD_NODEMCU 3
#define BOARD_CUSTOM 4
#define BOARD_WROOM32 5
#define BOARD_WEMOSD1MINI 6
#define BOARD_TTGO_TBASE 7
#define BOARD_ESP01 8
#define BOARD_SLIMEVR 9
#define BOARD_LOLIN_C3_MINI 10
#define BOARD_BEETLE32C3 11
#define BOARD_ES32C3DEVKITM1 12
#define BOARD_OWOTRACK 13  // Only used by owoTrack mobile app
#define BOARD_WRANGLER 14  // Only used by wrangler app
#define BOARD_MOCOPI 15  // Used by mocopi/moslime
#define BOARD_WEMOSWROOM02 16
#define BOARD_XIAO_ESP32C3 17
#define BOARD_HARITORA 18 // Used by Haritora/SlimeTora
#define BOARD_ES32C6DEVKITC1 19
#define BOARD_DEV_RESERVED 250 // Reserved, should not be used in any release firmware

#define BAT_EXTERNAL 1
#define BAT_INTERNAL 2
#define BAT_MCP3021 3
#define BAT_INTERNAL_MCP3021 4

#define LED_OFF 255

#define POWER_SAVING_LEGACY 0  // No sleeping, but PS enabled
#define POWER_SAVING_NONE 1  // No sleeping, no PS => for connection issues
#define POWER_SAVING_MINIMUM 2  // Sleeping and PS => default
#define POWER_SAVING_MODERATE \
	3  // Sleeping and better PS => might miss broadcasts, use at own risk
#define POWER_SAVING_MAXIMUM \
	4  // Actual CPU sleeping, currently has issues with disconnecting

// Send rotation/acceleration data as separate frames.
// PPS: 1470 @ 5+1, 1960 @ 5+3
#define PACKET_BUNDLING_DISABLED 0
// Less packets. Pack data per sensor and send asap.
// Compared to PACKET_BUNDLING_DISABLED, reduces PPS by ~54% for 5+1, by ~63% for 5+3
// setups. PPS: 680 @ 5+1, 740 @ 5+3
#define PACKET_BUNDLING_LOWLATENCY 1
// Even less packets, if more than 1 sensor - wait for data from all sensors or until
// timeout, then send. Compared to PACKET_BUNDLING_LOWLATENCY, reduces PPS by ~5% for
// 5+1, by ~15% for 5+3 setups. PPS: 650 @ 5+1, 650 @ 5+3
#define PACKET_BUNDLING_BUFFERED 2

// Get radian for a given angle from 0° to 360° (2*PI*r, solve for r given an angle,
// range -180° to 180°)
#define DEG_X(deg) ((((deg) < 180.0f ? 0 : 360.0f) - (deg)) * PI / 180.0f)

//used in "sensor.h", see sensorOffset
#define DEG_0 DEG_X(0.0f)
#define DEG_90 DEG_X(90.0f)
#define DEG_180 DEG_X(180.0f)
#define DEG_270 DEG_X(270.0f)

#define CONST_EARTH_GRAVITY 9.80665

#define ACCEL_CALIBRATION_METHOD_SKIP 0
#define ACCEL_CALIBRATION_METHOD_ROTATION 1
#define ACCEL_CALIBRATION_METHOD_6POINT 2

#define BMI160_MAG_TYPE_HMC 1
#define BMI160_MAG_TYPE_QMC 2
#define BMI160_MAG_TYPE_QMP 3

#define MCU_UNKNOWN 0
#define MCU_ESP8266 1
#define MCU_ESP32 2
#define MCU_OWOTRACK_ANDROID 3  // Only used by owoTrack mobile app
#define MCU_WRANGLER 4  // Only used by wrangler app
#define MCU_OWOTRACK_IOS 5  // Only used by owoTrack mobile app
#define MCU_ESP32_C3 6
#define MCU_MOCOPI 7  // Used by mocopi/moslime
#define MCU_HARITORA 8  // Used by Haritora/SlimeTora
#define MCU_DEV_RESERVED 250  // Reserved, should not be used in any release firmware

#ifdef ESP8266
#define HARDWARE_MCU MCU_ESP8266
#elif defined(ESP32)
#define HARDWARE_MCU MCU_ESP32
#else
#define HARDWARE_MCU MCU_UNKNOWN
#endif

#define CURRENT_CONFIGURATION_VERSION 1

#endif  // SLIMEVR_CONSTS_H_

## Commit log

2025-06-10 Add references and work on schematic
    [FBT.kicad_pcb, FBT.kicad_sch, LX-LBES.step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]
2025-06-10 More schematic work
    I'm kind of hung up on what charging circuit to use...
    [FBT.kicad_pcb, FBT.kicad_sch, tiny-slime.kicad_sch]
2025-06-16 work on PCB and shell
    [FBT.kicad_pcb, Shell.blend, tiny-slime.kicad_sch]
2025-06-19 Add firmware from SVR
    unmodified
    [Configuration.h]
2025-06-21 Switch to SVR firmware 0.5.2
    0.6.0 has some problems with my MCU (crash-on-startup)
    [Configuration.h]
2025-06-21 more tweaks and changes
    [FBT.kicad_pcb, Shell.blend]
2025-06-21 Work on housing
    [Shell.blend]
2025-06-22 create driver for QMC5883P
    Amazon scammed me
    Todo next: integrate this into the SVR firmware
2025-06-22 Magnetometer now interfaces with the IMU
    Still doesn't show up in SVR server for some reason...
    [QMC5883P.h, bmi160sensor.cpp, bmi160sensor.h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]
2025-06-22 clean up sensor implementation
2025-06-23 Bump firmware version to 0.5.4
    Tried 0.6.0, but that crashes on the esp32-C3.
    0.5.4 is the latest stable release though, so I'll go with that for now.
    [Configuration.h]
2025-06-23 Bring over changes from the 0.5.2 firmware
    Don't quite know why 0.5.4 broke the first time, but it works now.
    [bmi160sensor.cpp, bmi160sensor.h, consts.h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]
2025-06-23 Re-work PCB and add more IMU refs
    Trying to make this as dynamic as possible
    [FBT.kicad_pcb, FBT.kicad_sch]
2025-06-25 Measurements, notes, tweaks
    Finding and fixing problems as I get ready to order parts for these
    [FBT.kicad_pcb]
2025-06-25 schematic work and notes
    [FBT.kicad_pcb, FBT.kicad_sch]
2025-06-26 split schematic and mark firmware
    Planning to make 2 types of PCB layouts for different kinds of batteries.
    Also marked points in the firmware that are of particular interest to me (getting/sending magnetometer status to the frontend)
    [FBT.kicad_pcb, FBT.kicad_sch]
2025-06-30 Work on silkscreen logo
    Made a mascot, "Mr. Tracker" which looks a lot like Mr. Lunt mixed with Pa Grape.
    [FBT.kicad_pcb, FBT.kicad_sch]
2025-07-01 Work on shell and PCB
    Needed to do more work on the extended tracker
    [FBT.kicad_pcb]
2025-07-02 work on PCBs, logos, and case
    did more work on 18650 battery model
    [FBT.kicad_pcb, FBT.kicad_sch, IMU_Extender.kicad_sch]
2025-07-08 Work on 18650 PCB
    It's done, but I may re-do this one to flip the ESP32 sideways...
    (I then proceeded to work on the sideways version)
    [FBT.kicad_pcb, FBT.kicad_sch]
2025-07-08 straggling files
    why weren't these committed with the others?
    [FBT_shortways.kicad_pcb]
2025-07-09 Final touches for fabrication
    Sent designs off to JLBPCB... hopefully they work...
    [FBT-B_Cu.gbl, FBT-B_Mask.gbs, FBT-B_Paste.gbp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]
2025-07-11 Rework MrTracker footprint to support the big lx-lbes
    [FBT.kicad_pcb, FBT.kicad_sch]
2025-07-11 work on correcting Ms. Tracker
    it has to be a little bit bigger unfortunately...
    [FBT.kicad_pcb, FBT.kicad_sch]
2025-07-15 prep v2 PCB for production
    [FBT-B_Cu.gbl, FBT-B_Mask.gbs, FBT-B_Paste.gbp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]
2025-07-17 Bugfix QMC5883P and work on LSM6DS3 support
    I forgot to map the QMP data to the output. oops.
    [bmi160sensor.cpp]
2025-08-05 PCB updates and some firmware testing
    Also begin finalizing the 3d model for the tracker case.
    I've decided to flip it upside down.
    [defines.h, main.cpp]
2025-08-11 More CAD work
    printing tests and resizing
    [FBT.kicad_pcb, ShellTest.stl, StrapLoop.stl]
2025-08-13 More size fitting
    [FBT2.stl, ShellTest.stl]
2025-08-26 Undo flip transform and debug magnetometer
    Turns out the flip transform can already be done with axis remaps. This solves some other problems I've been having as well.
    I'm still struggling to get magnetometer orientation correct though.
    [Configuration.h, Shell.blend, Shell.stl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]
2025-08-26 Add test framework for checking magnetometer flux
    prefixed all unneeded modifications with //test:
2025-08-26 Add nearly exhaustive list of remaps to try
    I feel like I could do this a better way, but oh well... I guess it gets the job done
    I'm not smart enough for better methods currently
2025-08-27 some slight work on LSM6ds3 sensor
    mainly adding annotations
2025-09-05 Axis remapping for main IMUs and extenders
    Lots of debug comments and support for live remapping.
    Also some basic implementation stuff for the lsm6ds3 as well (though I think the complete implementation is on my other computer)
2025-09-06 add ability to enable and disable mag for BMI160
    Todo: send magnetometer vector to the computer. The program lists this packet type as deprecated, so I don't know if this is possible.
    The desktop app seems to have support to display it, but there's nothing in the core to take data from the tracker and throw it out in a format the frontend likes.
    also moved old lsm6ds3 implementation to backups since the sensor fusion one should work and I don't have one to test with.
2026-01-05 Move unused firmwares into subfolder
    [Configuration.h]
2026-01-17 Start editing schematic for better power supply
    removed diodes and experimenting with multiple LDOs for supplying power from all inputs
    [FBT.kicad_sch]
2026-02-07 more lsm6ds3 testing
    brought in STM reference to see how they set up secondary sensors
    [Shell.blend]
2026-02-07 Got magnetometer reading working
    can now read a QMC5883P from out of an LSM6DS3
    up next is making it work with slimeVR
2026-02-09 add magnetometer interface to sensorFusion
    todo: magnetometer calibration and code format compliance for the LSM6DS3.
    (also re-added axis remapping to the main code)
2026-02-10 Got the LSM6DS3 working correctly with magnetometer
    I need to put this into the upstream firmware.
    I also need to add the proper enable / disable functions to the preprocessor config. I'm currently mooching off of the BMI160 stuff.
    [bmi160sensor.cpp, consts.h, defines.h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]
2026-02-10 Add better documentation
    It's still not good, but something is better than nothing.
    [LX-LBES.step, lxlbes_ref.blend]
2026-03-18 Update schematic to v3
    Added support for a discrete LDO (HT7333) so we can correct the bodge we did with the original design.
    [FBT.kicad_pcb, FBT.kicad_sch, FBT_shortways.kicad_pcb]
2026-03-23 Slight PCB tweaking
    Double-checking that everything is correct before I ship off the next batch for fabbing.
    Added a jumper pad between usb-c 5v inputs.
    [FBT.kicad_pcb, FBT.kicad_sch]
2026-06-11 Export the next revision of PCBs for fabrication
    Made at JLCPCB
    Also picked apart the LSM6DS3 datasheet some more. Apparently, the auto hard/soft iron compensation isn't dynamic. It depends on pre-calculated matrices fed into the IMU's registers.
    [FBT-B_Cu.gbl, FBT-B_Mask.gbs, FBT-B_Paste.gbp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]
2026-07-02 Work a little on the shell
    Also add mag frequency to the debug output in the firmware
    [Shell.blend]
2026-07-14 Work on extender case and docs
    [ExtenderShell.stl, ExtenderStrapLoop.stl, Extender_v2_BasePlate.stl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]
2026-07-18 Work on documentation, fix Mr. Tracker Jumpers
    The Rev 3.0 PCB unfortunately can't accommodate all regulator configs due to a mistake in the pin layout (forgetting which pins went where in the schematic)
    This was resolved for Mr. Tracker
    TODO: Mrs. Tracker
    [FBT.kicad_pcb, FBT.kicad_sch]
2026-07-21 Documentation updates
    Still much more to add though. Need to take pictures of the latest rev tracker boards.
